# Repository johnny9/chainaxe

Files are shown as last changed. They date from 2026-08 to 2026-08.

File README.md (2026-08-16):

# ChainAxe — Rev A.1



Status: **engineering prototype; not a manufacturing release**  
Updated: 2026-08-16

ChainAxe is a clean-room ESP32-S3 controller for:

- one full S19- or S21-family Bitmain hashboard through the common data cable;
- four AntHat-style 12 V, four-wire Antminer fans with tach feedback and fail-safe full-speed startup;
- a 12–15 V low-current controller input; and
- native USB, Wi-Fi, and an ESP-Miner-derived mining application.

ChainAxe is an independent open-hardware project and is not affiliated with or endorsed by Bitmain. Antminer is a trademark of its respective owner.

The name refers to the complete ASIC hash chain controlled by the board. ChainAxe supersedes the earlier FT4232HQ-based **bitcrane** prototype with a clean ESP32-S3 architecture intended to run ESP-Miner directly.

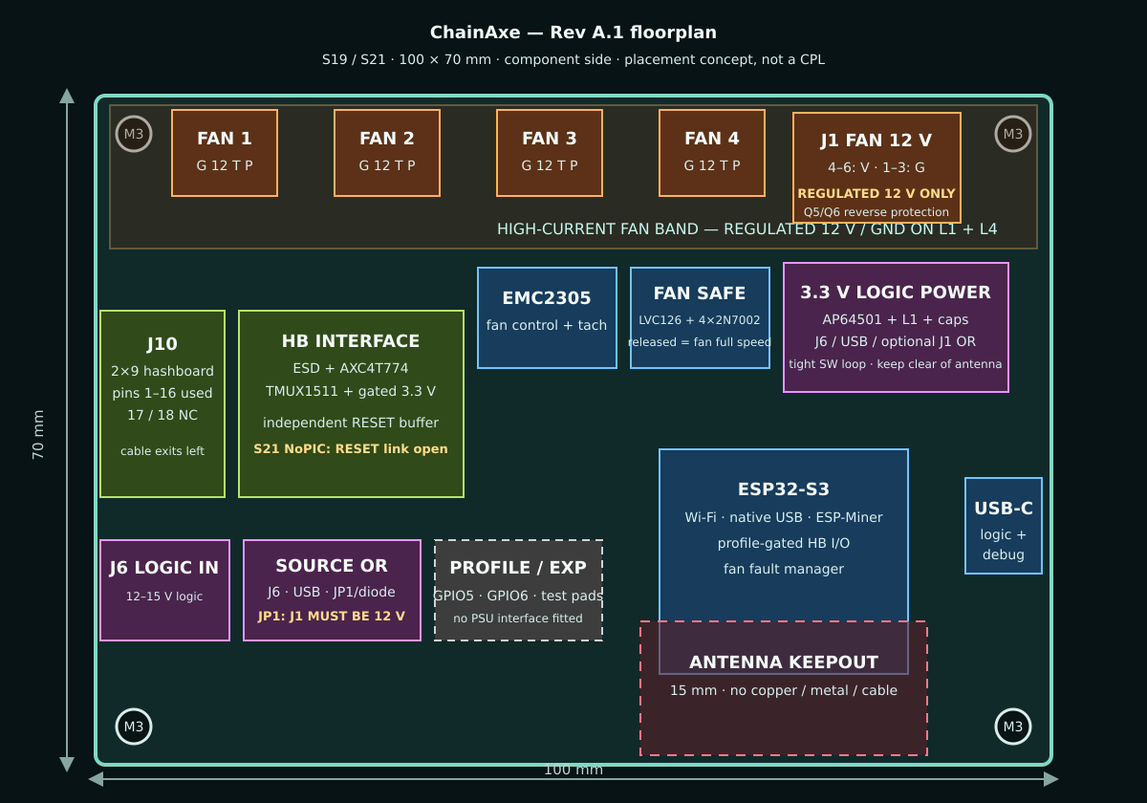
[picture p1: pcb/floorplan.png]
ChainAxe Rev A.1 PCB floorplan


There is **no PSU communication interface in Rev A.1**. Hashboard ASIC/core power remains on its normal external bus bars or bench supply. The ESP board communicates only through the hashboard data cable and drives the four fan connectors.

## Connector interpretation

The retained hashboard connector is physically **2×9 / 18 positions**. Pins 1–16 are used and positions 17–18 are NC, which explains the shorthand “16-pin header.” The user has confirmed this interface is compatible across the intended S19/S21 targets, so Rev A.1 standardizes the cable-side logic domain at 3.3 V and removes the previous target-voltage population matrix.

Compatibility here means the connector and electrical interface are shared. Firmware must still select the correct ASIC family, chip count, address stride, baud sequence, reset policy, and voltage/temperature-control path for the exact hashboard SKU.

## What is here

| Area | Deliverable |
|---|---|
| Architecture | Rail, signal, safety, and power-up decisions in `docs/architecture.md` |
| Target matrix | S19/S21 ASIC/profile scope in `docs/target-matrix.md` |
| Interfaces | Hashboard, fan, power, and USB pin tables in `docs/connector-pinout.md` |
| Schematic entry | Sheet plan and explicit net map in `schematic/` |
| BOM | JLC-oriented engineering BOM and upload template in `bom/` |
| PCB start | 100 × 70 mm floorplan, placement table, stack-up, and routing rules in `pcb/` and `docs/pcb-layout.md` |
| Firmware | ESP-Miner multi-profile porting plan in `firmware/esp-miner-porting-plan.md` |
| Release gates | Review and first-power checklist in `design-review-checklist.md` |
| Validation | Frozen hashes, automated results, and explicit open gates in `VALIDATION.md` |
| Provenance | Repository commits, licenses, and primary datasheets in `sources.md` |

## KiCad project

The editable KiCad 9 baseline is under `hardware/chainaxe/`:

- `chainaxe.kicad_pro` — project and net-class settings;
- `chainaxe.kicad_sch` — preliminary electrical schematic; and
- `chainaxe.kicad_pcb` — 100 × 70 mm unrouted placement baseline.

The KiCad files are intended for engineering review and iteration. They are not released Gerbers. Parts marked provisional or TBD in the engineering BOM must be resolved, the exact connector footprints must be fit-checked, and ERC/DRC must pass in KiCad before an order is placed. KiCad's CLI is not available in this workspace, so the included automated structural, pin-map, and placement-geometry checks are not ERC/DRC results.

The BOM distinguishes exact part candidates from provisional and TBD choices. There are no Gerbers, CPL, or fabrication ZIPs because the exact connector footprints, fan current path, and first supported hashboard profile still require engineering signoff.

## Rev A.1 block architecture

```mermaid
flowchart TD
    F12["12 V fan input"] --> FUSE["External fuse"]
    FUSE --> RPP["Reverse-polarity FETs"]
    RPP --> FANS["Four AntHat-style fan headers"]
    VIN["12–15 V logic input"] --> BUCK["3.3 V logic buck"]
    F12 -. "optional link at 12 V only" .-> BUCK
    USB["USB-C 5 V"] --> BUCK
    BUCK --> ESP["ESP32-S3"]
    ESP --> FANCTL["EMC2305 + fail-safe sinks"]
    ESP --> HBIO["3.3 V gated hashboard interface"]
    HBIO --> HB["18-position / 16-used cable"]
```

The hashboard's ASIC/core current does **not** pass through this controller. Controller ground, fan ground, and hashboard data-cable ground must be common.

## Power-input decision

- `J1 FAN_12V_IN`: high-current, regulated 12 V for the four fans.
- `J6 VIN_LOGIC_12_15`: low-current 12–15 V input for the AP64501 logic regulator.
- `JP1 FAN_TO_LOGIC`: optional fitted link/diode that powers logic from J1 when J1 is verified 12 V.
- USB-C can power logic for flashing with J1/J6 disconnected.

This split is intentional. A nominal 12 V fan must not receive 15 V unless its actual datasheet explicitly permits it. A single 12 V source can power both rails by fitting JP1; a 13–15 V hashboard system needs a separate regulated 12 V fan feed or a future high-current 12 V converter.

## Primary target profiles

- S19 XP / S19k-class BM1366 boards: ASIC driver exists in ESP-Miner; full-board chip counts and power control remain profile-specific.
- S21 BM1368 boards: ASIC driver exists; standard S21 evidence uses 108 chips and requires a NoPIC-aware startup path.
- S21 Pro / S21 XP / S21+ BM1370 boards: chip driver exists; each SKU has a different chip count.
- BM1398 and BM1362 S19-family boards require new ESP-Miner drivers before mining, even though the connector hardware is compatible. The family name alone is not sufficient to select the ASIC.

See `docs/target-matrix.md` for exact scope and evidence levels.

## Recommended first article

1. Review the KiCad schematic pin-by-pin, fit-check every connector and project-local footprint against current manufacturer drawings and real mating parts, and run ERC.
2. Assemble USB, ESP32-S3, AP64501, EMC2305, fan buffer/sinks, and the standardized 3.3 V hashboard interface.
3. Hand-install the 12 V fan, 12–15 V logic, fan, and hashboard connectors on five boards.
4. Validate USB-only and logic-only power first.
5. Validate four genuine Antminer fans from the dedicated 12 V input.
6. Bring up one named hashboard profile with core power current-limited and mining disabled until enumeration, temperatures, and fan interlocks pass.

## Key design choices

- ESP32-S3-WROOM-1-N16R8 retains ESP-Miner's UART pins 17/18.
- A SN74AXC4T774-class buffer operates at 3.3 V on both sides and provides explicit interface enable/disable.
- TPS22917 supplies connector pin 16 with controlled turn-on and reverse-current blocking.
- TMUX1511 is powered from switched `HB_3V3` and uses two of its powered-off-protected channels for the hashboard I²C pair. Local pull-ups stay on controller `3V3`; cable-side pull-ups stay on `HB_3V3`, so an unpowered cable domain cannot be phantom-powered through SDA/SCL.
- RESET has no universal hardware pulldown. Its bias and use are profile-dependent, and the series `RESET_ENABLE_LINK` is DNP/open in the default S21-safe assembly. It is populated with 33 Ω only for a specifically validated legacy-reset profile.
- EMC2305 outputs pass through a disabled-by-default SN74LVC126 and four 2N7002 sinks. With the ESP or buffer unpowered, fan PWM lines float and the fans run full speed.
- Fan motor power uses a calculated low-loss reverse-polarity FET stage, short wide top-and-bottom pours, and an upstream external fuse; it never flows through the AP64501.
- USB D+/− must be routed for 90 Ω differential, ±10%, over continuous ground; the ESP antenna sits at the board edge with a 15 mm keepout.

## Repository conclusions

- `bitaxeNaja` remains useful for ESP32-S3 pin conventions and translated ASIC I/O, but its dual-BM1340 chain is not a full-hashboard reference.
- `aditBoard` supplies the common 18-position/16-used connector map.
- `AntHat` supplies the EMC2305 fan-control pattern and the requested four 12 V fan connector arrangement. Its PSU section is not used.
- Current ESP-Miner supplies BM1366, BM1368, and BM1370 drivers but not BM1398 or BM1362.

## Licensing boundary

This is an original starter specification and does not redistribute the KiCad files or footprint artwork from `aditBoard` or `AntHat`, whose repositories do not state a hardware license. `bitaxeNaja` is CERN-OHL-S-2.0 and ESP-Miner is GPL-3.0; copying their covered hardware or software into a later release carries the corresponding obligations. See `sources.md`.

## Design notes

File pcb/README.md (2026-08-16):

# PCB start

- `floorplan.svg` is the Rev A.1 visual placement concept.
- `floorplan.png` is a rendered review copy of the same drawing.
- `placement.csv` records the synchronized major-block centers from the Rev A.1 KiCad baseline in a board-relative 100 × 70 mm coordinate system.

These are **not** centroid/CPL files and do not enumerate every passive. Final production coordinates must be exported from the routed PCB after connector mating-face orientation and rotations are verified.

The top high-current band distributes regulated 12 V from J1 to four AntHat-style fan connectors. The 12–15 V J6 logic input is a separate low-current domain; the optional JP1/diode feed may link the fan rail into the logic OR only when J1 is truly 12 V. USB can power logic independently.

The common 2×9 hashboard connector uses positions 1–16 and leaves 17/18 NC. Its UART/PLUG translator, I²C switch, gated 3.3 V source, and independent RESET buffer are fitted. The series RESET link is DNP/open in the default S21-safe assembly; fit it only for an exact legacy-reset profile that has passed bench validation.

There is no PSU-control interface in this revision. Consequently the PCB cannot guarantee hard removal of hashboard core power. Fault handling must stop work, use a verified hashboard-local shutdown command if available, disable cable I/O as the profile permits, and release fan PWM for full speed; failed local shutdown requires external power removal.

The module antenna shown at the lower edge assumes that edge is outside a metal enclosure. If the controller is fully inside an Antminer chassis, change U1 to a validated ESP32-S3 external-antenna module and recheck RF compliance and the BOM.

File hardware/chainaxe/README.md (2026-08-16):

# ChainAxe KiCad project

This directory contains the editable Rev A.1 KiCad baseline.

## Files

- `chainaxe.kicad_pro` — KiCad project settings and provisional net classes.
- `chainaxe.kicad_sch` — annotated preliminary schematic.
- `chainaxe.kicad_pcb` — 100 × 70 mm unrouted placement baseline.
- `chainaxe.kicad_dru` — conservative prototype rules.
- `pin-net-audit.csv` — exhaustive expected/actual connection contract for every schematic pin.
- `symbols/ChainAxe.kicad_sym` and `sym-lib-table` — project-local custom symbols.
- `ChainAxe.pretty/` and `fp-lib-table` — nine pinned project-local manufacturer-derived/audited footprints.

Open `chainaxe.kicad_pro` in KiCad 9. KiCad may update generated metadata when the project is first saved; review that diff before committing it.

The source package is structurally checked by `scripts/validate_design.py`. The exhaustive `pin-net-audit.csv` contract is independently checked against physical symbol-pin endpoints by `scripts/validate_schematic_pinmap.py`; that validator explicitly converts KiCad library Y-up coordinates to schematic Y-down coordinates. `scripts/validate_pcb_geometry.py` checks different-net pad intersections, NPTH/copper conflicts, body/courtyard collisions, and undocumented edge overhangs. All three are dependency-free CI checks. This build environment does not include `kicad-cli`, so a local KiCad 9 ERC/DRC run remains mandatory before any fabrication export; none of the source validators replaces it.

Fan startup is hardware-defined: R105 holds `FAN_ARM` low, while R106–R109 hold the four EMC2305 PWM inputs to U8 low. This keeps the open-drain fan sinks released (the supported-fan full-speed-safe state) even if firmware asserts `FAN_ARM` before configuring the EMC2305. J30's audit enumerates every USB4105-GF-A signal/power contact; its A9/B9 VBUS and A12/B12 ground contacts are stacked on their shared logical nets. The official footprint numbers all four conductive shell stakes as `S1`, so one audited `S1` pin owns that common shell net.

C112 is the populated 100 nF USBLC6 VBUS bypass and must sit directly beside U9 pins 5/2. C3, the optional 220 µF 3V3 bulk footprint, is native DNP until AP64501 loop and load-transient validation proves an appropriate bulk value.

## Design status

This is an engineering-entry design, not an order-ready board. The schematic and PCB capture the intended architecture, safe startup states, connector map, and major candidate parts. The following remain release blockers:

- real-mating-part fit and keyed circuit-view checks for J1, J2–J6, J10, and USB-C; J6's exact connector/part remains a stop-order choice;
- fan current, inrush, reverse-polarity FET, connector, copper, and thermal calculations;
- AP64501 feedback, compensation, inductor, capacitance, and thermal verification;
- ESD/TVS clamping analysis and final ordering codes;
- exact first hashboard SKU/profile, including RESET policy and local voltage-off behavior;
- KiCad ERC, PCB synchronization, routing, stack-up impedance calculation, and DRC; and
- JLCPCB assembly preview, BOM/CPL reconciliation, and first-article review.

Do not generate production Gerbers from this baseline without closing the stop-order gates in `../../design-review-checklist.md`.

## PCB intent

The PCB is intentionally unrouted. The fan-current band stays at the top/right edge, the J10 interface lane stays at the left edge, and the ESP32-S3 antenna faces the bottom board edge with a 15 mm keepout. The `USB_90OHM_PLACEHOLDER` and `FAN_POWER_PROVISIONAL` net classes are reminders, not validated geometries.

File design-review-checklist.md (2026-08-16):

# Rev A.1 design-review and release checklist

Any unchecked item in **Stop-order gates** blocks Gerber/CPL release.

## Stop-order gates

- [ ] At least one initial profile is frozen with exact miner SKU, hashboard assembly/revision, ASIC type/count, PIC/NoPIC architecture, and captured factory startup sequence.
- [ ] J10 is a common keyed 2×9, 18-position cable connector; positions 1–16 match the documented map and 17/18 are confirmed NC.
- [ ] TX, RX, PLUG, SDA, SCL, pin-16 3.3 V, and profile-specific RESET behavior are verified on the exact target.
- [ ] S21 BM1368 NoPIC assembly leaves `RESET_ENABLE_LINK` open, and its profile is also proven never to enable the independent RESET buffer in boot, operation, watchdog, update, restart, and fault paths.
- [ ] Initial and operational UART baud, ASIC enumeration count, voltage-control path, telemetry, and local shutdown command are established per supported profile.
- [ ] Exact AntHat-style fan MPN, connector/key orientation, 12 V current, startup/stall current, tach pulses/revolution, and safe minimum RPM are recorded.
- [ ] J1 is labeled and protected for exact regulated 12 V fan power; J6 is labeled and protected for 12–15 V logic power.
- [ ] J1 pins 1–3 are GND and 4–6 are `FAN_12V_RAW`, matching the reviewed AntHat source and the final mating-face drawing.
- [ ] Q5/Q6 reverse-polarity FET count, SOA, current sharing, Rds(on), copper, and thermals pass measured simultaneous fan startup/stall current.
- [ ] JP1 cannot connect J1 to logic without an explicit `12V ONLY` assembly choice, and every J1/J6/USB combination is reverse-isolated.
- [ ] System-level safety review accepts that this revision cannot hard-remove hashboard core power and documents the external disconnect procedure.

## Schematic review

- [ ] Every external cable line has an intentional default state and connector-side ESD decision.
- [ ] U5/TPS22917 is populated; source/sink direction, reverse current, rise time, QOD choice, and pin-16 load are checked.
- [ ] U6/SN74AXC4T774 is populated; channel directions, `/OE` polarity, Ioff/partial-power behavior, and maximum profile baud are checked.
- [ ] U7/TMUX1511 is populated from `HB_3V3`; its exact TSSOP-14 pin map, powered-off isolation, two used channels, grounded unused selects, 100 nF decoupling, pull-ups, and enable sequencing are checked.
- [ ] Hashboard I²C rise time, low-level sink current, bus capacitance, and overshoot are measured at 100 kHz and the intended operating rate; `HB_I2C_EN` is low before every `HB_3V3` ramp.
- [ ] U12 RESET buffer has an enable independent of U6 and defaults high-impedance with an ESP reset or unpowered.
- [ ] No fixed pull-up/pull-down on HB_RESET can violate an S21 NoPIC profile; any optional bias is visibly DNP/profile-specific.
- [ ] Every A0/A1/A2 high strap connects only to switched `HB_3V3`; the corresponding low/high population pair cannot be fitted incorrectly.
- [ ] The default S21-safe DNP RESET link provides a firmware-independent open circuit during ESP bootloader, brownout, crash, update, and USB-only operation.
- [ ] J10 pins 17 and 18 are electrically NC.
- [ ] AP64501 feedback, inductor, input/output capacitance after DC bias, transient response, loss, and thermal rise are calculated over J6 = 12–15 V.
- [ ] Logic-source OR cannot backfeed USB, J1, or J6; USB-only power leaves fan sinks released, HB_3V3 off, UART/I²C disabled, and RESET high-impedance.
- [ ] JP1 and its diode are rated for the logic load and not treated as a way to operate 12 V fans from 15 V.
- [ ] EMC2305 address and hardware 100%-speed startup decode are checked against the current datasheet.
- [ ] Fan-driver polarity is traced end-to-end: command → EMC output → buffer → NMOS → fan PWM input.
- [ ] `FAN_ARM` defaults inactive and cannot assert before verified 100% command/readback.
- [ ] `EMC_PWM1..4` each have a populated 100 kΩ pulldown at U8, and the early-arm fault case is bench-tested to keep fan PWM released/full speed.
- [ ] Every supported fan is proven to provide a compatible internal PWM pull-up and to request full speed when the controller sink is released; Rev A.1 has no external PWM pull-up rail.
- [ ] ESP strapping pins 0/3/45/46 are not used for operational safety outputs.
- [ ] No PSU-control connector, enable circuit, bus, GPIO assignment, or misleading power-cut label remains.
- [ ] ERC has no unexplained power, unconnected, or conflicting-driver warnings.

## PCB / mechanical review

- [ ] Manufacturer drawings are used for every high-current and cable connector footprint.
- [ ] 1:1 paper fit and real mating-connector fit are complete for J1, J2–J6, J10, and J30.
- [ ] J30's drawing-derived USB4105-GF-A footprint is verified by 1:1 print and real-part fit, including every VBUS/GND contact, through-hole shell stake, locating peg, board-edge datum, and pin-1 orientation.
- [ ] J10 mating-face pin 1, 2×9 keying, and no-connect positions 17/18 match the cable.
- [ ] Fan pin 1 and `G 12 T P` functions are visible after assembly and match the AntHat-style harness.
- [ ] `FAN 12V ONLY` and `LOGIC 12–15V` are distinct, legible labels; JP1 carries a `CLOSE ONLY WITH 12V J1` warning.
- [ ] Selected JLC four-layer stack is entered in KiCad and USB is solved for 90 Ω differential, ±10%.
- [ ] L2 is continuous ground under USB, UART, I²C, tach, ESP, and buck control routes.
- [ ] ESP antenna is outside/at the chassis boundary with 15 mm copper/component/metal/cable keepout, or U1 is changed to a validated external-antenna module.
- [ ] Fan-current path is reviewed from the upstream external fuse/wiring through J1 contacts, Q5/Q6, pad, neck, pour, via field, and each branch connector.
- [ ] IPC-2152/current-density analysis uses measured simultaneous startup/stall current and selected copper weight.
- [ ] Prototype thermography confirms connector, fuse, pour, and via-field temperature rise at worst case.
- [ ] Buck hot loop and SW node are compact; FB is quiet; exposed-pad thermal vias and paste windows are reviewed.
- [ ] J1, J6, USB, fan, and hashboard ESD/TVS returns reach connector ground without crossing sensitive logic returns.
- [ ] U12 and its 33 Ω RESET resistor are routed independently from UART enable and placed close to the J10 interface.
- [ ] DRC passes final JLC rules; there is no silkscreen over pads and solder-mask slivers meet the chosen process.

## BOM / JLC assembly review

- [ ] Every LCSC code is reopened at quote time and matched to manufacturer, exact MPN, package, lifecycle, and stock.
- [ ] Basic/extended/THT handling and minimum quantities are accepted.
- [ ] DNP and hand-install lists agree across schematic, BOM, CPL, assembly drawing, and README.
- [ ] U5, U6, U7, U12, their default-enable resistors, and connector-side protection are fitted in the intended Rev A.1 variant.
- [ ] JP1 is open by default and assembly notes prevent automatic solder bridging.
- [ ] CPL rotation/side and pin 1 are inspected in JLC's assembly preview for every fitted part.
- [ ] QFN exposed-pad and THT paste openings are inspected; no accidental open-hole paste remains.
- [ ] A five-board first article is ordered and reviewed before volume assembly.

## Bring-up / DVT

- [ ] Bare-board continuity and isolation pass between FAN_12V, VIN_LOGIC_12_15, LOGIC_IN, USB_VBUS, 3V3, and HB_3V3.
- [ ] Current-limited USB-only, J6 = 12 V, J6 = 15 V, and J1 = 12 V power-ups pass before J10/fans are installed.
- [ ] No test applies more than 12 V to J1 or the fan connectors.
- [ ] Hardware defaults are measured before firmware: fan PWM sinks released, HB_3V3 off, UART/I²C disabled, RESET high-impedance, and JP1 open.
- [ ] Four fans start at full speed before `FAN_ARM`; every unplug/stall produces the expected fault.
- [ ] Hashboard cable is first tested with core power disabled and all interface outputs disabled.
- [ ] Each released profile enumerates its configured ASIC count on 100 cold starts and has clean readback at its final baud.
- [ ] S19 XP/S19k-class BM1366, S21 BM1368, and BM1370-family testing is tracked as separate profiles rather than inferred from connector compatibility.
- [ ] Fault injection stops work, attempts verified local shutdown when supported, disables cable I/O as permitted, preserves profile-safe RESET behavior, and releases fans to full speed.
- [ ] A failed local shutdown test explicitly demonstrates and documents the required external hashboard power removal.
- [ ] A 24-hour conservative mining soak passes before frequency/voltage exploration for each released profile.

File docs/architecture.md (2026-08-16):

# Rev A.1 architecture

Rev A.1 is an ESP32-S3 miner/controller for one S19- or S21-family Bitmain hashboard and four AntHat-style 12 V fans. It talks to the hashboard only through the common data cable. Hashboard ASIC/core power remains on the external bus bars; there is no PSU connector, PSU enable signal, or PSU telemetry interface on this revision.

This is a schematic-entry architecture, not a production-qualified power controller. Every mining-capable firmware build must select one exact, tested hashboard profile.

## System boundary

```mermaid
flowchart TD
    FANIN["J1: regulated 12 V"] --> RPP["Reverse-polarity FETs"]
    RPP --> FANBUS["Protected fan bus"]
    FANBUS --> FH["Four 4-wire fans"]
    VIN["J6: logic 12-15 V"] --> ORING["Logic-input OR"]
    USB["USB-C 5 V"] --> ORING
    FANBUS -. "JP1; 12 V only" .-> ORING
    ORING --> BUCK["AP64501 3.3 V"]
    BUCK --> ESP["ESP32-S3 + fan control"]
    ESP --> HBIO["Gated 3.3 V cable I/O"]
    HBIO --> HB["S19/S21 hashboard"]
```

The controller does not carry hashboard core current. Fan return, controller ground, and hashboard cable ground are common; the external hashboard power system must share that reference.

## Power domains

| Domain | Source | Intended load | Design rule |
|---|---|---|---|
| `FAN_12V` | `J1 FAN_12V_IN` through Q5/Q6 | Four fan motor supplies | Regulated 12 V only; size connector, reverse-polarity FETs, fuse, pours, and wiring from the actual fan nameplate current and inrush |
| `VIN_LOGIC_12_15` | `J6` | Controller logic | 12–15 V, low current; protected before the logic-input OR node |
| `USB_5V` | USB-C | Controller-only bring-up | Must not backfeed J1, J6, fan motor power, or hashboard pin 16 |
| `LOGIC_IN` | diode/ideal-diode OR of J6, USB, and optional J1 link | AP64501 input | Source isolation is required; populate `JP1 FAN_TO_LOGIC` only when J1 is a verified 12 V rail |
| `3V3` | AP64501 | ESP32-S3, EMC2305, buffers, sensors | Local logic rail |
| `HB_3V3` | 3V3 through TPS22917 | Hashboard cable pin 16 | Default off; reverse-current blocking; enabled only after a profile and cable checks pass |

A 15 V source must never be routed directly to nominal 12 V fans. A single regulated 12 V supply can feed both J1 and the logic regulator when JP1 is deliberately fitted. For a 13–15 V system, provide a separate regulated 12 V fan source; a future revision could add a high-current fan buck after the current requirement is known.

Recommended protection at schematic entry:

- an upstream, replaceable external fuse sized for all fan startup current and located close to the 12 V source;
- a low-loss high-current P-channel MOSFET reverse-polarity stage on J1, starting with two parallel `DMP3013SFV-7` candidates plus a gate resistor/Zener clamp; one device is not assumed to carry four-fan startup current, and the final FET count/thermal design must follow measurement;
- a series Schottky reverse-block/OR diode on J6 and a bidirectional `SMBJ18CA`-class provisional TVS so a normal reversed input does not forward-bias the shunt protector;
- an `SMBJ13A`-class starting TVS candidate on the protected 12 V fan bus, with standoff, clamp, pulse energy, and fan tolerance verified before release;
- bulk capacitance beside the fan input and each connector group, and local high-frequency decoupling at every IC; and
- no copper path that makes the AP64501 carry fan motor current.

## Hashboard cable interface

J10 is physically 2×9 / 18 positions. Positions 1–16 carry the common Bitmain signals and 17–18 are NC. Rev A.1 treats every cable-side logic signal as 3.3 V; exact pin mapping is in `connector-pinout.md`.

| Function | Circuit | Safe default |
|---|---|---|
| Pin-16 supply | TPS22917 load switch from 3V3 | Off by GPIO10 pulldown; reverse-current blocking |
| UART TX/RX and `PLUG` | SN74AXC4T774-class buffer, both sides at 3.3 V | Disabled by GPIO7 pull-up on active-low OE |
| SDA/SCL | Two channels of TMUX1511, powered by switched `HB_3V3`; local pull-ups to `3V3`, cable pull-ups to `HB_3V3` | Powered-off isolation when `HB_3V3` is absent; GPIO9 pulldown keeps both selects low |
| RESET | Independent SN74LVC1G125-class tri-state buffer plus DNP series `RESET_ENABLE_LINK` | Physical cable path open in the default S21-safe assembly; 10 kΩ pull-up also keeps the buffer high-impedance |
| A0/A1/A2 | 4.7 kΩ default-low straps plus mutually exclusive solder options to switched `HB_3V3` | Address 0; any nonzero setting is an explicit assembly/profile choice; never strap to always-on 3V3 |

The reset path is intentionally separate from the UART/plug buffer. GPIO1 carries the reset command and GPIO4 separately enables the reset driver. A 10 kΩ pull-up keeps the active-low enable inactive. There is no universal populated pull-up or pull-down on the cable RESET net; optional bias pads are DNP until the exact target proves a safe value. The series `RESET_ENABLE_LINK` is also DNP/open by default, which makes the first S21 BM1368 NoPIC assembly physically incapable of driving J10 RESET. A legacy-reset profile may populate that link with 33 Ω only after its exact reset sequence is validated. Public S21 work warns that legacy GPIO reset can collapse the hashboard's TAS5782M DAC-generated voltage.

Series resistors near the controller should be fitted on push-pull cable outputs, with footprints for damping adjustment after scope measurements. Put low-capacitance ESD parts at J10 without creating stubs. The connector shell/key/orientation and mating part remain procurement signoff items even though the signal map is fixed.

U7 is deliberately not a conventional dual-rail I²C level translator. The TMUX1511 is a bidirectional signal switch with powered-off protection to 3.6 V and fail-safe select inputs. Supplying it from `HB_3V3` makes both I²C paths high-impedance whenever the hashboard I/O supply is off, even while the controller-side pull-ups remain at 3.3 V. Only channels 1 and 2 are used; channels 3 and 4 are held off. The two 4.7 kΩ pull-up pairs appear in parallel while enabled, so the effective pull-up is about 2.35 kΩ. Firmware must deassert `HB_I2C_EN` before intentionally ramping `HB_3V3`, and the real cable must be checked for rise time, low-level margin, capacitance, and overshoot below the switch's 3.6 V powered-off limit.

## Fan subsystem

Each of four connectors follows the AntHat-style logical order `GND, +12V, TACH, PWM` and must use the same proven physical family and orientation at schematic release. The EMC2305 monitors tach and produces four PWM commands. Each command passes through a disabled-by-default SN74LVC126 stage and an external 2N7002 open-drain sink:

- `FAN_ARM` (GPIO8) is held low by hardware until firmware has configured and read back the EMC2305;
- 100 kΩ pulldowns on `EMC_PWM1..4` hold the buffer inputs low while the EMC2305 outputs are still open-drain at power-on, so even an erroneous early `FAN_ARM` leaves the external PWM sinks released;
- when the ESP, EMC2305, or buffer is unpowered, the sink gates remain inactive and PWM wires float;
- supported four-wire fans therefore use their internal pull-ups and request full speed on a floating PWM line; fans that do not provide a compatible internal PWM pull-up are outside the Rev A.1 supported profile.

Tach inputs need ESD protection, optional RC filtering, and voltage clamps compatible with the EMC2305 input limits. Firmware must validate tach age and plausible RPM on all configured required fans before mining.

## GPIO allocation

| GPIO | Function |
|---:|---|
| 1 | Hashboard RESET command input to independent tri-state buffer |
| 4 | `HB_RESET_OE_N`; pulled high |
| 5, 6 | Reserved expansion/test pads |
| 7 | Active-low hashboard UART/PLUG buffer OE; pulled high |
| 8 | `FAN_ARM`; pulled low |
| 9 | Hashboard I2C switch enable; pulled low |
| 10 | Hashboard pin-16 3.3 V enable; pulled low |
| 11 | Protected/divided rail monitor ADC |
| 12 | Hashboard `PLUG` input |
| 13 | EMC2305 ALERT input |
| 14, 21 | Hashboard SDA/SCL |
| 17, 18 | ASIC UART TX/RX |
| 47, 48 | Local EMC2305 SDA/SCL |

USB uses the ESP32-S3 native USB pins and must follow Espressif's routing and antenna guidance.

## Startup and fault ownership

Hardware pull resistors establish a safe state before the ESP boots: fans request full speed, hashboard pin 16 is off, UART/I2C/reset drivers are high-impedance, and mining is impossible. One firmware safety state machine owns every interface enable and the `mining_allowed` decision.

Because Rev A.1 intentionally omits PSU control, it cannot guarantee removal of externally supplied hashboard core power. On a fault it can stop sending work, issue a tested hashboard-local I2C shutdown/voltage-off command when the selected profile supports one, disable cable interfaces in the profile-defined safe order, and release fan PWM for full-speed cooling. If the local shutdown path is absent or fails, the external supply must be disconnected by the operator or an independent protection system. This limitation must remain visible in the UI and release documentation.

## Profile boundary

Connector compatibility does not make the ASIC protocol universal. Each firmware profile must fix at least the ASIC family, chip count, address stride, initial and operating baud, reset policy, I2C devices, voltage-control sequence, temperature interpretation, and shutdown behavior. Unknown or ambiguous boards remain in diagnostic mode. The current priority is BM1368 S21, followed by exact BM1366 S19 XP/S19k profiles and then BM1370 S21 variants; see `target-matrix.md`.

## PCB consequences

- Keep the high-current fan band at the board edge and away from USB, the ESP antenna, UART, tach, and I2C routing.
- Route J1-to-fan power with short top-and-bottom pours and dense via stitching; calculate width and connector temperature rise from the measured worst-case current.
- Keep J6/logic protection and AP64501 switching loops compact and physically separate from fan PWM/tach and the ESP antenna.
- Place all J10 protection, series resistors, translators, and load switch in one short interface lane at the cable connector.
- Expose test points for J1, J6, LOGIC_IN, 3V3, HB_3V3, fan PWM/tach, UART, I2C, RESET, all OEs, and ground.
- Preserve the ESP module's board-edge antenna position and 15 mm copper/component keepout.

## Release blockers

Before fabrication release, capture the exact S19/S21 cable connector manufacturer/part number, fan connector family/orientation, fan maximum current and inrush, protection ratings, AP64501 magnetics/compensation, exact first hashboard SKU, and a verified local voltage-off path. Before enabling mining, prove interface waveforms, full-chain enumeration, thermal sensing, all four fan-fault paths, watchdog behavior, and the limitations of shutdown without PSU control.

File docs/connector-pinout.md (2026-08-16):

# Connector pinout and cable rules

All connector drawings and silkscreen must identify the **mating-face view**. A bottom-mounted or right-angle connector can mirror what the designer sees in KiCad. Verify orientation, keying, and pin 1 with continuity testing before applying power.

## J10 — common Bitmain hashboard data cable

Rev A.1 uses the common 2×9, 2.00 mm, 18-position Bitmain data connector. The electrical interface occupies positions 1–16; positions 17 and 18 remain no-connect. This preserves the cable form used by the target S19/S21 families even though it is often informally called a “16-pin” interface.

Proposed connector: right-angle female `PM200-2-09-W-4.3` / LCSC `C3012192`, pending a real-cable fit check and a manufacturer-drawing footprint audit.

| Pin | Net | Rev A.1 treatment | Direction at controller |
|---:|---|---|---|
| 1 | GND | Cable ground | — |
| 2 | GND | Cable ground | — |
| 3 | HB_SDA | TMUX1511 powered-off-protected switch; cable pull-up to `HB_3V3` | Bidirectional |
| 4 | HB_SCL | TMUX1511 powered-off-protected switch; cable pull-up to `HB_3V3` | Bidirectional |
| 5 | HB_PLUG | SN74AXC4T774 channel, ESD protected | Input |
| 6 | HB_A2 | 4.7 kΩ default low; mutually exclusive option to switched `HB_3V3` | Static strap |
| 7 | HB_A1 | 4.7 kΩ default low; mutually exclusive option to switched `HB_3V3` | Static strap |
| 8 | HB_A0 | 4.7 kΩ default low; mutually exclusive option to switched `HB_3V3` | Static strap |
| 9 | GND | Cable ground | — |
| 10 | GND | Cable ground | — |
| 11 | HB_TX | SN74AXC4T774 channel + 33 Ω source resistor | Output to hashboard |
| 12 | HB_RX | SN74AXC4T774 channel + 33 Ω damping resistor | Input from hashboard |
| 13 | GND | Cable ground | — |
| 14 | GND | Cable ground | — |
| 15 | HB_RESET | Independent tri-state reset buffer through `RESET_ENABLE_LINK` | Physical link DNP/open for default S21-safe assembly; fit 33 Ω only for a validated legacy-reset profile |
| 16 | HB_3V3 | Controller-supplied 3.3 V through U5/TPS22917 | Power output |
| 17 | NC | No connection | — |
| 18 | NC | No connection | — |

U5, the UART/PLUG translator, and the I²C switch are populated in Rev A.1. Their enables default inactive so an unconfigured ESP cannot drive the cable. The reset path has a separate output-enable signal from the normal UART enable; a profile may use UART and I²C while leaving RESET electrically high-impedance.

### Reset rule

RESET is not a universal startup primitive. The selected hashboard profile owns its polarity, level, timing, and whether it may be driven at all. In particular, the S21 BM1368 NoPIC assembly leaves `RESET_ENABLE_LINK` open and its firmware must **never enable the controller reset buffer**. A firmware update or fault handler must not bypass this rule.

### Cable validation

1. With both systems unpowered, trace cable pin 1 to ground and establish the mating-face orientation.
2. Confirm that positions 17 and 18 are unused on the exact board and cable.
3. Record the exact miner model, hashboard assembly/revision, ASIC type/count, and original-controller startup capture.
4. Power Rev A.1 with the hashboard's core rail off for the first interface test. Confirm 3.3 V at pin 16 and high-impedance UART/I²C/RESET before enabling one interface at a time.
5. Do not connect an unprofiled or unknown hashboard merely because the cable fits.

## J2–J5 — AntHat-style 12 V four-wire fans

Use the AntHat 2×2 candidate, Molex `0353180420` / LCSC `C54909`, and match the actual fan harness before releasing the footprint. Redraw it from Molex's current drawing rather than copying AntHat's custom combo footprint. Print the electrical order beside every connector as `G 12 T P`; do not rely on wire color.

| Pin | Signal | Notes |
|---:|---|---|
| 1 | GND | High-current motor return |
| 2 | FAN_12V | Exact regulated 12 V motor rail from J1 |
| 3 | TACHn | Open-collector/open-drain tach; pulled to 3.3 V |
| 4 | PWMn | External 2N7002 open-drain control; hardware default released for full speed |

Connector views in fan documentation can show these functions in the opposite visual order. Treat that as an orientation issue, not permission to swap functions. Validate pin 1, keying, power polarity, tach pulses/revolution, and PWM behavior on the actual AntHat fan before mating it to Rev A.1.

## J1 — regulated 12 V fan input

J1 is the high-current fan input. It must receive a regulated **12 V** supply suitable for the measured simultaneous startup/stall current of all four fans. Do not feed J1 with 15 V.

Proposed connector: Molex `0455580003` / LCSC `C492365`, using a datasheet-derived 2×3 THT footprint with three contacts paralleled per rail. AntHat uses this part for its input, but Rev A.1 restricts it to regulated 12 V fan power.

| Pins | Net |
|---|---|
| 1, 2, 3 | GND |
| 4, 5, 6 | FAN_12V_RAW |

This polarity follows the reviewed AntHat source. `FAN_12V_RAW` passes through the Q5/Q6 reverse-polarity stage before it becomes the protected `FAN_12V` bus. Do not reuse AntHat's custom footprint: generate a fresh footprint from the connector manufacturer's current drawing, print it 1:1, and perform a real-part fit check.

## J6 — 12–15 V logic input

J6 is a separate, low-current input for the controller buck regulator.

| Pin | Net | Notes |
|---:|---|---|
| 1 | VIN_LOGIC_12_15 | 12–15 V DC input, protected before the logic-power OR |
| 2 | GND | Logic return |

JP1 and its series diode provide an optional `FAN_12V → LOGIC_IN` feed. Close JP1 only when J1 is known to be a regulated 12 V source. The controller may instead be powered from J6 or USB. The OR network must prevent any source from backfeeding USB, J6, or the fan rail.

## J30 — USB-C device/debug

USB 2.0 device-only receptacle:

- CC1 and CC2: separate 5.1 kΩ pull-downs to GND.
- D+/D−: USBLC6-2SC6-class low-capacitance ESD, then matched 22–33 Ω series resistors near the ESP.
- VBUS: logic-power OR input and VBUS sense only; never connected directly to J1 or J6.
- Schematic-owned contacts: A4/A9/B4/B9 = `USB_VBUS`; A1/A12/B1/B12 = `GND`; A5/B5 = CC1/CC2; A6/B6 = D+; A7/B7 = D−; A8/B8 = NC; all four conductive shell stakes share pad number S1 = `USB_SHIELD`, matching the official KiCad/GCT footprint.
- The project-local USB4105-GF-A footprint vendors the official KiCad 8.0.9/GCT drawing-derived geometry, including every duplicated contact, four through-hole shell stakes, and two locating pegs; a real-part first-article fit check remains mandatory.
- USB-only power must leave fan sinks released, HB_3V3 off, UART/I²C disabled, and RESET high-impedance.
- Shield: configurable chassis/ground treatment; initial 1 MΩ ∥ 1 nF option plus a short ESD return, subject to enclosure strategy.

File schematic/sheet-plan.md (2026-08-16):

# KiCad schematic-entry plan — Rev A.1

Create a hierarchical KiCad project with the following sheets. Rev A.1 is a direct S19/S21-family hashboard and four-fan controller; it has no PSU communication or PSU-enable interface.

## Sheet 1 — root / connectors

- J1 regulated 12 V high-current fan input (`FAN_12V`); this rail must not exceed the connected fans' rating.
- J6 low-current 12–15 V controller input (`VIN_LOGIC_12_15`).
- JP1 optional fan-rail-to-logic-input feed, fitted only when J1 is a verified regulated 12 V source.
- J2–J5 AntHat-style four-wire 12 V fan headers, silk-labeled `G / 12 / T / P`.
- J10 common Bitmain 2×9, 18-position hashboard data connector; positions 1–16 active and 17–18 NC.
- J30 USB-C for native USB and optional logic power.
- Hierarchical pins for each functional sheet.
- Four mounting holes, fiducials, and a labeled test-point table.

## Sheet 2 — power

- Three-source logic-input OR: J6 through D1, the JP1-qualified J1 feed through D2, and USB VBUS through D3.
- AP64501 3.3 V buck and complete compensation/feedback cell.
- J1 `FAN_12V_RAW` through two provisional parallel Q5/Q6 high-side P-channel reverse-polarity FETs, with gate resistor and 12 V Zener clamp, then D4 on the protected `FAN_12V` bus. Recalculate FET count and copper from measured current.
- J6 series D1 reverse-block/OR diode and a bidirectional D5 TVS appropriate to 12–15 V. Do not join the high-current fan path to the logic-input path except at the explicit JP1/D2 option.
- U5 TPS22917, populated, switches controller 3.3 V to `HB_3V3` and J10 pin 16.
- Rail-monitor divider, RC filter, and labeled test points.
- Copper/fusing note: J1 and J2–J5 carry fan current; J6, JP1, and the OR diodes carry controller current only.

## Sheet 3 — ESP32-S3

- ESP32-S3-WROOM-1-N16R8.
- Native USB protection and source-series resistors.
- EN RC/reset button and GPIO0 boot button.
- Debug UART/test pads; GPIO5 and GPIO6 reserved as labeled expansion/test pads.
- Local bulk and high-frequency decoupling.
- Explicit no-connects and antenna keepout note.

## Sheet 4 — hashboard interface

- U6 SN74AXC4T774-class 3.3 V-to-3.3 V gated interface for UART TX, UART RX, and PLUG.
- U7 TMUX1511PWR powered-off-protected switch, supplied by switched `HB_3V3`; use channels 1 and 2 for SCL/SDA, tie both selects to `HB_I2C_EN`, ground unused selects, and leave unused signal pins NC.
- 4.7 kΩ pull-ups on controller SCL/SDA to always-on `3V3`, and separate 4.7 kΩ cable-side pull-ups to switched `HB_3V3`.
- U12 independent SN74LVC1G125-class reset buffer: GPIO1 is reset data and GPIO4 is active-low output enable.
- 10 kΩ pullup on `HB_RESET_OE_N`; no fixed connector-side reset pulldown. Provide mutually exclusive optional bias pads and leave them DNP.
- DNP/open `RESET_ENABLE_LINK` between U12 and the cable-side 33 Ω position. The default S21-safe assembly leaves this physical path open; populate 33 Ω only for a validated legacy-reset target.
- Large schematic warning: the S21 BM1368 NoPIC profile must leave the link open and never enable or toggle U12.
- A0/A1/A2 default-low resistors and mutually exclusive high straps to switched `HB_3V3` only; never to always-on `3V3`.
- Connector-side ESD arrays and 33 Ω source-series options.
- Safe-state pulls on U5 enable, U6 OE, U7 enable, and U12 OE.

## Sheet 5 — fan controller

- EMC2305 with exposed pad, decoupling, 22 kΩ `CLK`, and 33 kΩ `ADDR_SEL` straps.
- SN74LVC126-class buffer disabled by `FAN_ARM` at reset, with 100 kΩ pulldowns on all four `EMC_PWM` inputs, followed by four 2N7002 open-drain PWM sinks.
- No controller-side PWM pull-up rail; supported AntHat-style four-wire fans must provide their own compatible PWM pull-ups.
- Four 36 kΩ tach pull-ups to 3.3 V.
- ALERT pull-up and test points.
- `FAN_ARM` hardware pulldown, four buffer-input pulldowns, and individual MOSFET gate pulldowns.
- Optional RC/ESD footprints at external fan signal lines; populate only after signal-integrity review.

## Sheet 6 — expansion / test

- Labeled GPIO5/GPIO6 expansion pads with ground and 3.3 V nearby.
- Programming/debug access and test points for all rails and external signals.
- Profile/assembly-variant identification pads.
- No PSU connector, PSU control net, or PSU communications circuitry.

## ERC conventions

- Name every voltage domain: `FAN_12V`, `VIN_LOGIC_12_15`, `USB_VBUS`, `LOGIC_IN`, `3V3`, and `HB_3V3`.
- Use net ties only where a documented single-point connection is required; do not silence ERC with generic power flags.
- Mark DNP alternatives with assembly variants and mutually exclusive population groups.
- Add a note beside every external connector specifying the drawing view and pin-1 indicator.
- Include source URL, datasheet revision, and footprint-drawing revision as symbol/footprint properties for critical parts.

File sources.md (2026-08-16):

# Source and license record

Accessed 2026-08-16. Repository commits are pinned where a reviewed revision was available. Part availability, board variants, and external documentation can change; revalidate them before design release.

## Requested hardware repositories

### bitaxeNaja

- Repository: https://github.com/bitaxeorg/bitaxeNaja
- Reviewed master commit: `6d815ef05288b3079a94567eb02c4e73d85dd82d`
- License: CERN Open Hardware Licence Version 2 — Strongly Reciprocal (`CERN-OHL-S-2.0`).
- Applicable facts: ESP32-S3-WROOM-1-N16R8 conventions, native USB implementation, and buffered ASIC signals.
- Boundary: Naja is a short, dual-BM1340 chain and is not proof of signal integrity, power sequencing, or firmware behavior on a full S19/S21 hashboard.

### aditBoard

- Repository: https://github.com/skot/aditBoard
- Production v2 revision reviewed: https://github.com/skot/aditBoard/tree/1c260d8767b7821e2b2d7aa110d65c469ff71d2d
- Firmware reference: https://github.com/skot/aditboard-firmware
- No hardware license was found in the repository. Use it as interface evidence; do not copy or redistribute its KiCad artwork or custom footprints without permission.
- Applicable facts: common 2×9 / 18-position cable connector, with signal positions 1–16 and positions 17–18 NC; USB/UART/I2C/GPIO bridge topology.
- Boundary: its firmware is a bridge rather than a miner, and the exact cable connector manufacturer/part number still needs procurement verification.

### AntHat

- Repository: https://github.com/skot/AntHat
- Master revision reviewed: `5a05b5dd6bb5a9b8b767a26e3bf38c463c0e4669`
- Newer v3 branch head inspected: `24fcf0eb23e5fd2e0015a6cf52990735f914ed60`
- No hardware license was found. Redraw circuits/footprints from manufacturer documentation or obtain permission before copying source artwork.
- Applicable facts: EMC2305 fan-control concept, four 12 V four-wire fan interfaces, logical fan pin order `GND, 12V, TACH, PWM`, Molex `0353180420` / LCSC `C54909` as the 2×2 fan-connector candidate, and Molex `0455580003` / LCSC `C492365` as its input connector. The reviewed source assigns input pins 1–3 to GND and 4–6 to VIN, and uses a DMP3013SFV-based reverse-polarity stage; Rev A.1 expands that stage provisionally for the four-fan load.
- Boundary: Rev A.1 intentionally does not use AntHat's PSU section.

## Hashboard and firmware evidence

- ESP-Miner baseline: https://github.com/bitaxeorg/ESP-Miner/tree/d3dbcc51d11d33b7579baac8c5b9808a4a112790
  - License: GPL-3.0.
  - `device_config.h`: https://github.com/bitaxeorg/ESP-Miner/blob/d3dbcc51d11d33b7579baac8c5b9808a4a112790/main/device_config.h
  - The reviewed baseline exposes BM1397, BM1366, BM1368, and BM1370 ASIC drivers. It does not expose BM1362 or BM1398 drivers.
  - Its current newer-ASIC implementations and UART17/18 convention are starting points, not full-hashboard profiles.
- ESP-Miner S19 XP investigation: https://github.com/bitaxeorg/ESP-Miner/issues/248
  - Records one 110-chip BM1366 S19 XP example and useful initialization discussion. Treat it as one board variant, not a universal count.
- DCENT_OS platform notes: https://github.com/DCentralTech/DCENT_OS/blob/main/DCENT_OS_Antminer/docs/PLATFORMS.md
  - Used to associate established Antminer families with BM1398, BM1362, BM1366, BM1368, and BM1370 generations. Family labels span revisions, so exact board identity still controls.
- DCENT_OS S21 BM1368 profile: https://github.com/DCentralTech/DCENT_OS/blob/main/DCENT_OS_Antminer/dcentrald/dcentrald-silicon-profiles/src/bm1368.rs
  - Records a 108-chip, three-chain S21 profile, 3.125 Mbaud Bitmain operation, and a NoPIC warning: GPIO-resetting the chain can kill the TAS5782M DAC voltage. Rev A.1 therefore has an independent reset output-enable and keeps it disabled for S21 NoPIC.
- Third-party current model catalog: https://github.com/molepool/GMiner-Molepool-Asic-Release
  - Used only as variant/count evidence for exact-profile planning: examples include BM1366 S19 XP at 70/99/110 chips, S19k Pro at 77, BM1368 S21 at 108, and BM1370 S21 variants at 55/65/91.
  - This is not silicon-vendor documentation and does not establish a safe voltage, frequency, reset sequence, or connector rating.

## Primary component and layout sources

- Espressif ESP32-S3-WROOM-1 / WROOM-1U module datasheet: https://www.espressif.com/sites/default/files/documentation/esp32-s3-wroom-1_wroom-1u_datasheet_en.pdf
  - Module land pattern, 3.7 mm center pad and via array, antenna-end orientation, and antenna keepout used for the project-local footprint.
- Espressif ESP32-S3 PCB layout guidance: https://docs.espressif.com/projects/esp-hardware-design-guidelines/en/latest/esp32s3/pcb-layout-design.html
  - Board-edge antenna placement, 15 mm antenna keepout, continuous USB reference plane, and 90 Ω ±10% USB differential routing.
- Microchip EMC2301/2/3/5 datasheet: https://ww1.microchip.com/downloads/aemDocuments/documents/MSLD/ProductDocuments/DataSheets/EMC2301-2-3-5-Data-Sheet-DS20006532A.pdf
  - Four-wire fan support, PWM output configuration, tach measurement, startup strap behavior, and electrical limits.
- Diodes Inc. AP64501 datasheet, DS41980 Rev. 5-2: https://www.diodes.com/datasheet/download/AP64501.pdf
  - 3.8–40 V, 5 A synchronous buck candidate for the low-current logic rail. Its SO-8EP pin map, feedback equation, soft-start recommendation, compensation network, magnetics, output capacitance, and thermal behavior control the Rev A.1 implementation.
- TI TPS22917 datasheet, SLVSDW8B: https://www.ti.com/lit/gpn/TPS22917
  - Gated pin-16 3.3 V supply with reverse-current blocking; pin 4 is CT, pin 5 is QOD, and pin 6 is switched VOUT.
- TI TMUX1511 datasheet, SCDS390B: https://www.ti.com/lit/gpn/TMUX1511
  - Four-channel bidirectional switch with powered-off protection to 3.6 V, fail-safe select inputs, and internal select pulldowns. Rev A.1 powers it from `HB_3V3`, uses two channels for SCL/SDA, and adds an external enable pulldown.
- TI SN74AXC4T774 datasheet, SCES898C: https://www.ti.com/lit/gpn/SN74AXC4T774
- TI SN74LVC1G125: https://www.ti.com/product/SN74LVC1G125
- TI TPD4E05U06 datasheet/package drawing, SLVSBO7O: https://www.ti.com/lit/gpn/TPD4E05U06
  - DQA0010A signal lands, enlarged ground lands, pin numbering, and NC pins used for the cable-ESD footprint.
- ST USBLC6-2SC6: https://www.st.com/en/protections-and-emi-filters/usblc6-2.html
- Diodes Inc. DMP3013SFV datasheet: https://www.diodes.com/assets/Datasheets/DMP3013SFV.pdf
  - PowerDI3333-8 package pins 1–3 are source, pin 4 is gate, and pins 5–8 are drain. The reverse-input topology must be checked against that physical package map and diode-mode tested before fabrication.
- onsemi BZX84C12LT1G product/datasheet: https://www.onsemi.com/products/discrete-power-modules/zener-diodes/bzx84c12l
  - The SOT-23 map is pin 1 anode, pin 2 NC, pin 3 cathode. Rev A.1 uses it from the P-FET gate to protected `FAN_12V`; the 250 mW rating and clamp current need calculation and transient verification.
- Bitmain fan overview: https://support.bitmain.com/hc/en-us/articles/4402395808409-General-knowledge-and-Recurring-problem-about-Fan
  - General evidence that S19-family fans are four-wire 12 V units; the exact fan label/datasheet controls current, connector, pulses/revolution, and speed limits.
- Molex 0455580003 sales drawing SD-45558-001: https://www.molex.com/content/dam/molex/molex-dot-com/products/automated/en-us/salesdrawingpdf/455/45558/455580003_sd.pdf
  - J1 contact pitch, hole diameters, retention pegs, and circuit-1 orientation.
- Molex 0353180420 sales drawing SD-35318: https://www.molex.com/content/dam/molex/molex-dot-com/products/automated/en-us/salesdrawingpdf/353/35318/353180420_sd.pdf
  - J2–J5 unequal row/column pitch, hole diameters, and circuit numbering.
- GCT USB4105 drawing: https://gct.co/files/drawings/usb4105.pdf
- KiCad 8.0.9 USB4105 footprint: https://gitlab.com/kicad/libraries/kicad-footprints/-/blob/8.0.9/Connector_USB.pretty/USB_C_Receptacle_GCT_USB4105-xx-A_16P_TopMnt_Horizontal.kicad_mod
  - Drawing-derived USB-C signal lands, locating pegs, shell stakes, courtyard, and board-edge datum. KiCad footprint-library material is distributed under CC BY-SA 4.0; any vendored copy remains under that license.

## JLCPCB/LCSC references

- JLCPCB KiCad BOM/CPL export guide: https://jlcpcb.com/help/article/how-to-generate-the-bom-and-centroid-file-from-kicad
- JLCPCB BOM/CPL matching guidance: https://jlcpcb.com/help/article/common-bom-and-cpl-matching-issues-and-explanations
- Candidate LCSC pages:
  - ESP32-S3-WROOM-1-N16R8: https://www.lcsc.com/product-detail/C2913202.html
  - AP64501SP-13: https://www.lcsc.com/product-detail/C2071517.html
  - EMC2305-1-AP-TR: https://www.lcsc.com/product-detail/C621415.html
  - TMUX1511PWR: https://www.lcsc.com/product-image/C2866750.html
  - BZX84C12LT1G: https://www.lcsc.com/product-detail/C82475.html
  - USBLC6-2SC6: https://www.lcsc.com/product-detail/C7519.html
  - TPS22917DBVR: https://www.lcsc.com/product-detail/C2681320.html

These are sourcing candidates, not a frozen AVL. Confirm package, lifecycle, stock, JLC basic/extended status, substitutions, voltage ratings, and thermal limits at quotation time. Provisional TVS, connectors, power diodes, magnetics, fan-current protection, and reset-buffer ordering codes intentionally remain TBD in the engineering BOM.

## Clean-room and licensing boundary

This package records public interface facts and new engineering decisions. It intentionally contains no copied KiCad schematic, PCB, Gerber, or custom footprint file from the unlicensed aditBoard or AntHat repositories. If a later implementation copies CERN-OHL-S-2.0-covered Naja hardware or incorporates GPL-3.0-covered ESP-Miner code, distribute the required corresponding source and notices under those licenses.

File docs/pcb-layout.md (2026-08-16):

# PCB floorplan and routing brief

## Board and stack-up

- Outline: 100.0 × 70.0 mm, 1.6 mm finished thickness.
- Four copper layers: L1 signals/power, L2 uninterrupted GND, L3 quiet logic power with fan-rail exclusions, and L4 signals/power.
- Copper: request 2 oz outer layers if supported by the selected JLC four-layer stack; 1 oz inner layers is acceptable. Recalculate fan-current temperature rise after the stack is fixed.
- Finish: ENIG is preferred for the EMC2305 exposed-pad QFN and prototype rework; lead-free HASL is acceptable after assembly-yield review.
- Prototype rules: begin at 0.15/0.15 mm track/space and 0.30 mm finished drill in a 0.60 mm via, unless the selected JLC capability is more conservative.
- Mounting: four M3 holes at (4,4), (96,4), (4,66), and (96,66) mm. Set plated/NPTH and copper clearance to the enclosure/chassis strategy.

The intended component placement is recorded in `pcb/placement.csv` and illustrated in `pcb/floorplan.svg`.

## Functional zones

| Zone | Approximate area | Rules |
|---|---|---|
| Four fan connectors and FAN_12V bus | y = 0–16 mm | Short, wide L1/L4 pours; dense stitching; no sensitive traces |
| J1 regulated 12 V fan input | x = 82–100, y = 10–32 mm | High-current connector, Q5/Q6 reverse-polarity FETs, and TVS coordinated with the upstream external fuse; multiple current-transfer vias and thermal copper |
| Fan controller and safe sinks | x = 42–72, y = 17–32 mm | Quiet tach reference; PWM NMOS devices close to fan fan-out |
| Logic buck | x = 74–96, y = 24–40 mm | Tight switch loop; keep SW copper small and away from antenna |
| Hashboard connector/interface | x = 0–38, y = 22–52 mm | J10 at edge; ESD first; gated 3.3 V, UART/I²C and independent RESET |
| J6 logic input and expansion | x = 0–40, y = 54–68 mm | Low-current 12–15 V input; separated from cable I/O; no PSU interface |
| ESP and USB | x = 62–100, y = 42–70 mm | Module antenna at bottom edge; 15 mm keepout |

## Placement order

1. Fix J1, J2–J6, J10, and J30 from manufacturer drawings and real mating plugs.
2. Put TVS/ESD devices between every external cable connector and the first active device.
3. Place AP64501, inductor, input/output capacitors, bootstrap, and feedback as one compact datasheet-derived cell. Keep FB away from SW.
4. Keep the protected J6 path, USB path, and optional JP1/diode fan-to-logic path distinct until the logic-power OR node.
5. Place EMC2305 and its decoupler between the fan signal routes but outside the fan motor-current return path.
6. Place U5, U6, U7, and U12 behind J10 protection. Keep U12 RESET output-enable independent from U6 UART enable.
7. Place the ESP32-S3 module at the bottom edge with the antenna projecting over or immediately adjacent to the edge.
8. Route USB first, then UART/RESET, I²C/tach, service nets, and finally fan power. Review return current in startup, stall, and fault states.

## Critical routing constraints

### USB and ESP antenna

- Solve D+/D− for 90 Ω differential, ±10%, using the selected JLC stack-up rather than a hard-coded width.
- Match D+/D− within 0.5 mm, use the same via count, avoid stubs, and maintain continuous L2 GND.
- Put ESD next to J30 and the 22–33 Ω resistors next to the ESP.
- Keep the module antenna at the board edge. No copper, planes, vias, traces, components, fasteners, cables, or enclosure metal within its 15 mm keepout.
- Do not route the fan bus, J6 input, or buck switch node behind the antenna.

### Hashboard signals

- Route TX/RX as single-ended 3.3 V CMOS, not as a differential pair.
- Keep TX/RX/RESET short and over solid ground. Put each 33 Ω source/damping resistor next to its driver/translator.
- Route RESET from U12 independently; do not merge its enable with the UART translator enable.
- Keep hashboard I²C together over ground and away from fan PWM edges.
- Put U5/TPS22917 close to J10 pin 16 and provide a local HB_3V3 test point.
- Stitch ground beside J10 pins 1, 2, 9, 10, 13, and 14 and beside protection-array returns.
- Leave pins 17 and 18 copper-free except for labeled no-connect pads.

### Fan motor power

- J1 accepts regulated 12 V only. J6 is the 12–15 V logic input; do not merge their upstream nets.
- Reserve at least a 12–14 mm board-edge band for FAN_12V and ground distribution.
- Use both outer layers and via stitching at 1.5–2.0 mm pitch around current-transfer necks, with multiple via rows at J1 and each fan branch.
- Treat every connector pad, reverse-polarity FET, neck, pour, and layer transition as part of the board current path, and include the upstream external fuse and wiring in the system review. A wide pour cannot rescue an undersized terminal or hot FET.
- Calculate simultaneous startup/stall current and temperature rise from the actual AntHat fans. The provisional design target is 12 A total, not a guaranteed rating.
- Route tach and PWM alongside quiet ground and never through a motor-return bottleneck.

### Logic power

- Keep the protected `FAN_12V`→JP1/D2, J6→D1, and USB→D3 paths visually and electrically separable before `LOGIC_IN`.
- JP1 must be inaccessible to accidental closure or carry an unmistakable `12V ONLY` silkscreen warning.
- Choose OR devices for reverse isolation across all unpowered-source combinations. Verify USB cannot backfeed J1/J6 and 12–15 V cannot reach VBUS.
- Minimize the buck high-di/dt loop: input ceramic → U3 VIN/PGND → switch → U3 PGND → input ceramic.
- Keep SW only large enough to connect U3 and L1. Place output capacitors immediately after L1 and route FB from the output-capacitor sense point away from SW.

## Suggested net classes

| Class | Nets | Start rule | Finalization |
|---|---|---|---|
| USB_DIFF | USB_DP, USB_DN | Solver-derived width/spacing | JLC stack and impedance review |
| FAN_PWR | FAN_12V, FAN_GND | L1/L4 pours | IPC-2152 plus prototype thermography |
| LOGIC_INPUT | VIN_LOGIC_12_15, LOGIC_IN | ≥0.75 mm where practical | OR-device/regulator current and surge analysis |
| LOGIC_PWR | 3V3, HB_3V3 | ≥0.50 mm where practical | Regulator/load-current calculation |
| HB_UART | HB_TX, HB_RX, HB_RESET | 0.20–0.25 mm | Scope edge quality at each profile baud |
| I2C_TACH | SDA/SCL/tach/alert | 0.20–0.25 mm | Rise-time check with final cable and pull-ups |
| GPIO | Remaining digital | 0.20 mm | Standard DRC |

## Assembly notes for JLCPCB

- Keep manufacturer MPN and LCSC code in separate fields. Footprint compatibility alone does not approve a substitute.
- Use explicit `DNP` fields for the optional fan pull-up rail, profile straps, and JP1; do not rely on omitted BOM rows.
- High-current and shrouded THT connectors may need hand installation or JLC wave/selective solder service.
- Inspect every rotation and side in JLC's assembly preview. Right-angle and bottom-inserted THT connectors need manual orientation review.
- Add labeled test pads for FAN_12V, VIN_LOGIC_12_15, LOGIC_IN, USB_VBUS, 3V3, HB_3V3, both I²C buses, TX, RX, RESET, RESET_OE_N, PLUG, and all tach/PWM channels.

## Fault-containment boundary

Rev A.1 has no PSU connection, so it cannot guarantee removal of the hashboard core supply. On a fault it can stop work submission, request the profile's hashboard-local voltage-off command when supported, disable cable interfaces, keep RESET behavior profile-safe, and release every fan PWM input for full speed. If local shutdown does not succeed, external removal of hashboard power is required. Placement, labels, and documentation must not imply a hard power-cut function that the PCB does not contain.

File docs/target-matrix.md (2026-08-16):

# S19/S21 target matrix

This matrix separates **connector compatibility** from **firmware readiness**. Rev A.1 uses one common 18-position/16-used, 3.3 V cable interface for all rows. A board is not allowed to mine until its exact SKU/profile defines chip family, chip count, address stride, UART sequence, reset behavior, and I²C voltage/temperature control.

| Miner family / example | ASIC | Typical chips per board | Current ESP-Miner chip driver | Rev A.1 status |
|---|---|---:|---|---|
| Legacy S19 / S19 Pro revisions | BM1398 | SKU-dependent | No | Connector-compatible; new driver required |
| S19 / S19 Pro / S19j-class BM1362 revisions | BM1362 | variants include 84, 88, 108, 120, or 126 | No | Connector-compatible; new driver required; model name alone is insufficient |
| S19 XP / S19j XP | BM1366 | variants include 70, 99, or 110 | Yes | Candidate after exact-SKU profile and full-chain tests |
| S19k Pro | BM1366 | commonly 77 | Yes | Candidate after exact-SKU profile and full-chain tests |
| S21 | BM1368 | commonly 108 | Yes | Preferred first S21 target; NoPIC-aware path required |
| S21 Pro | BM1370 | commonly 65 | Yes | Candidate after exact-SKU profile and reset/voltage proof |
| S21 XP | BM1370 | commonly 91 | Yes | Candidate after exact-SKU profile and reset/voltage proof |
| S21+ | BM1370 | commonly 55 | Yes | Candidate after exact-SKU profile and reset/voltage proof |

Counts are catalog/firmware evidence, not a substitute for reading the exact hashboard label/EEPROM, confirming its ASIC ID, and confirming enumeration. The same family name can span silicon and board revisions. Hydro, immersion, repair-class, and regional variants often use different counts and are outside the first-article scope.

## Recommended bring-up order

1. **S21 / BM1368 / 108 chips** — current ESP-Miner already has the chip driver, public full-board work identifies a 108-chip chain, and the main special case is explicit: do not apply legacy GPIO-reset behavior to the NoPIC/DAC power path.
2. **S19 XP / BM1366 / exact labeled count** — current chip driver exists, but the family has multiple chain counts and board revisions.
3. **BM1370 S21 variants** — driver exists, but use a distinct profile per exact SKU/count.
4. **BM1362 and BM1398 S19 variants** — hardware connector may be used, but firmware driver work comes first.

## Profile record required in firmware

Each supported hashboard must have an immutable profile containing:

- exact model/SKU string and accepted aliases;
- ASIC chip ID and expected response length;
- exact chip count and address stride;
- reset policy: `legacy_active_low`, `no_gpio_reset`, or another proven sequence;
- initial and operating UART baud plus register sequence;
- I²C devices, addresses, and pull-up assumptions;
- voltage enable/set/readback method, if present on the board;
- temperature sensor type, location, conversion, and limits;
- conservative frequency/voltage starting point;
- fan count and minimum airflow interlock; and
- tested shutdown and recovery order.

Runtime chip-ID detection may choose a driver, but it must not invent a chip count or power/reset policy. Ambiguous or unknown SKUs remain in management/diagnostic mode.

## Evidence notes

- Current ESP-Miner's ASIC enum and drivers include BM1366, BM1368, and BM1370, but not BM1362 or BM1398.
- ESP-Miner issue #248 records an S19 XP example with 110 BM1366 chips.
- DCENT_OS's S21 silicon profile records 108 BM1368 chips, 3.125 Mbaud Bitmain operation, and a NoPIC warning against legacy GPIO reset.
- Public third-party hashboard catalogs list multiple different counts within both S19 XP and S21-derived product names; exact SKU identity is therefore a required safety input.

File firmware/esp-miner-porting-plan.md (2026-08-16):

# ESP-Miner multi-profile porting plan — S19/S21

Baseline reviewed: `bitaxeorg/ESP-Miner` commit `d3dbcc51d11d33b7579baac8c5b9808a4a112790` (GPL-3.0). Rev A.1 should be added as a new board family with an explicit hashboard-profile layer; it must not masquerade as an existing Bitaxe device.

## Driver readiness

| Hashboard family | ASIC | Driver in reviewed ESP-Miner baseline | Initial work |
|---|---|---|---|
| Legacy S19 / S19 Pro revisions | BM1398 | No | Implement and validate a new ASIC driver before mining |
| S19 / S19 Pro / S19j-class BM1362 revisions | BM1362 | No | Implement and validate a new ASIC driver before mining |
| S19 XP / S19j XP / S19k Pro | BM1366 | Yes | Add one immutable profile per exact SKU/chip count and validate a full chain |
| S21 | BM1368 | Yes | Add the 108-chip profile and a NoPIC startup path that never drives RESET |
| S21 Pro / S21 XP / S21+ | BM1370 | Yes | Add separate profiles for their different chip counts and control paths |

The current enum/driver list is visible in ESP-Miner's [`device_config.h`](https://github.com/bitaxeorg/ESP-Miner/blob/d3dbcc51d11d33b7579baac8c5b9808a4a112790/main/device_config.h). An [ESP-Miner S19 XP issue](https://github.com/bitaxeorg/ESP-Miner/issues/248) provides evidence for one 110-chip BM1366 example, not a universal S19 XP count.

## Board GPIO contract

| Function | GPIO | Required firmware behavior |
|---|---:|---|
| Hashboard RESET command | 1 | Drive only through the independently gated reset buffer and only for profiles that explicitly permit it |
| `HB_RESET_OE_N` | 4 | Pull-up makes reset high-impedance; keep high for every `no_gpio_reset` profile |
| Expansion/test | 5, 6 | Leave high-impedance in Rev A.1 production firmware |
| Hashboard UART/PLUG `/OE` | 7 | Active low; external pull-up; enable only after profile selection |
| `FAN_ARM` | 8 | Active high; external pulldown; assert only after EMC2305 configuration and readback |
| Hashboard I2C switch enable | 9 | Active high; external pulldown; keep low before every `HB_3V3` ramp and until the switched rail is stable |
| Hashboard pin-16 3.3 V enable | 10 | Active high; external pulldown |
| Rail monitor | 11 | ADC; require calibrated, plausible values before mining |
| Hashboard `PLUG` | 12 | Debounce and interpret through the exact-board profile |
| EMC2305 ALERT | 13 | Interrupt plus periodic status polling |
| Hashboard SDA/SCL | 14 / 21 | Dedicated hardware I2C controller |
| ASIC UART TX/RX | 17 / 18 | UART1, 8-N-1; matches the reviewed ESP-Miner pin convention |
| Local EMC2305 SDA/SCL | 47 / 48 | Dedicated hardware I2C controller |

All enable GPIOs must be configured to their safe inactive state before any driver probes a bus.

## Profile schema

Create a compile-time table or signed configuration whose records cannot silently fall back to another model. Each profile needs:

- stable profile ID plus exact accepted label/EEPROM identifiers;
- ASIC model, expected response signature, exact chip count, address stride, and domain topology;
- reset policy such as `legacy_active_low` or `no_gpio_reset`, with timings only where measured;
- initial UART rate, register/baud-change sequence, operating UART rate, and verification transaction;
- I2C device addresses and a proven board-local voltage enable/set/readback/shutdown sequence;
- temperature sensor model, conversion, location, plausible range, stale limit, warning and trip limits;
- conservative starting voltage/frequency and bounded ramp steps;
- required fan count, pulses/revolution, minimum plausible RPM, spin-up time, and tach-stale limit; and
- tested startup, fault, cooldown, and recovery ordering.

Runtime ASIC-ID probing may corroborate a configured profile. It must not guess chip count, reset behavior, voltage protocol, or thermal limits from a family name. A missing, conflicting, or ambiguous identity leaves the unit in diagnostic mode.

## Work packages

1. Add an `chainaxe_reva1` board definition with the GPIO contract above and separate `i2c_local` and `i2c_hashboard` buses.
2. Introduce `hashboard_profile_t` and require an exact profile before any cable driver or pin-16 power is enabled.
3. Wrap the existing ASIC drivers behind profile operations for discover, address, set-baud, configure, submit work, read result, and stop.
4. Add an EMC2305 driver with output-type/polarity setup, four PWM/tach channels, tach-age tracking, ALERT decoding, and register readback before `FAN_ARM`.
5. Add `hashboard_power_ops` for board-local I2C `probe`, `enable`, `set_voltage`, `read_status`, `read_temperatures`, and `shutdown`. Do not emulate absent PSU control.
6. Make one high-priority safety task the sole owner of the hashboard OEs, reset OE, pin-16 enable, `FAN_ARM`, and `mining_allowed`.
7. Harden UART RX into a streaming parser that resynchronizes after partial/corrupt frames, validates length/CRC, and publishes error counters. Full-hashboard cables need stricter fault accounting than local Bitaxe traces.
8. Expose profile ID, detected ID/count, state, latched fault, fan RPM/age, temperature age, local-voltage status, UART errors, and recovery count through the UI/API.
9. Preserve ESP-Miner's GPL-3.0 notices and corresponding-source obligations in every distributed firmware image.

## Safety state machine

| State | Required actions and transition |
|---|---|
| `SAFE_BOOT` | Set `FAN_ARM=0`; pin-16 off; UART/PLUG and I2C switches disabled; reset buffer disabled; no jobs. Fan PWM drains float so compatible fans request full speed. |
| `LOCAL_CHECK` | Initialize local I2C, configure EMC2305 for the proven output polarity/mode, command 100%, read registers back, then assert `FAN_ARM`. Require plausible fresh tach from every required fan after spin-up. |
| `PROFILE_SELECT` | Require a configured exact SKU/profile, stable plug state, matching identity evidence, and no latched fault. Unknown or conflicting boards stop here. |
| `HB_IO_START` | Hold `HB_I2C_EN=0`; enable the gated pin-16 3.3 V rail; wait and verify it; then enable the TMUX1511 I2C paths and UART/PLUG paths in the selected profile's order. Reset remains high-impedance unless the profile later requests it. |
| `LOCAL_POWER_CHECK` | Probe the profile's hashboard-local controller/sensors; confirm safe voltage and fresh temperature data. If a local enable command is required, use only the proven per-profile sequence. |
| `ASIC_START` | For a legacy-reset profile, briefly enable the reset buffer and run its measured reset sequence. For S21 NoPIC, never enable the reset buffer and proceed with the bus-only initialization sequence. |
| `ENUMERATE` | Start at the profile's initial baud (normally 115200), enumerate valid responses, and require the exact expected count/IDs before address or clock changes. |
| `CONFIGURE` | Assign addresses, apply the exact ASIC register order, transmit the baud-change command at the old rate, wait for TX completion, switch the ESP UART, and prove the new link before ramping. |
| `MINING` | Accept work only while fan, temperature, plug, rail, identity/count, local-control, and UART-health interlocks remain current and valid. Ramp from a conservative voltage/frequency in bounded steps. |
| `FAULT_LATCHED` | Stop jobs; execute the tested board-local voltage-off/shutdown command if available; deassert the I2C switch before turning off `HB_3V3`; disable other cable paths in the profile-defined safe order; leave S21 reset untouched; release `FAN_ARM` for full-speed cooling; latch cause. |
| `RECOVERY` | Allow at most one conservative retry only for explicitly recoverable faults after a complete cooldown and healthy telemetry interval. Repeated or shutdown-path faults require manual acknowledgement and external power removal. |

An ESP reset or watchdog event must return to `SAFE_BOOT` through physical pulls before application code runs.

## Reset and UART rules

The S21/BM1368 path is a first-class special case, not a timing variation. The public [DCENT_OS S21 profile](https://github.com/DCentralTech/DCENT_OS/blob/main/DCENT_OS_Antminer/dcentrald/dcentrald-silicon-profiles/src/bm1368.rs) identifies a NoPIC design and warns that GPIO-resetting the chains kills the TAS5782M DAC voltage. Therefore an S21 profile keeps GPIO4 high and the reset buffer high-impedance from boot through fault handling.

Bring-up starts at 115200 unless an exact profile proves otherwise. The reviewed ESP-Miner drivers commonly transition newer ASICs to 1 Mbaud, while the public Bitmain-derived S21 profile records 3.125 Mbaud operation. Treat operating baud as profile data: send the ASIC baud command while the ESP is still at the old rate, wait for TX completion, switch the local UART, and validate register reads before accepting work. Do not select the faster number merely because the chip family can support it.

## Fault policy without PSU control

Rev A.1 has no means to disconnect the external hashboard core-power bus. Its strongest local response is to stop work, send a previously validated hashboard-local I2C voltage-off/shutdown command, disable cable interfaces where doing so is safe, and force fans to their fail-safe full-speed condition. If temperature rises, the local command NACKs, rail readback remains unsafe, or the board profile has no proven shutdown operation, firmware must display **EXTERNAL POWER REMOVAL REQUIRED** and remain latched. Documentation and UI must never describe this as a guaranteed hard shutdown.

Other mandatory trips:

- missing/stale/implausible fan tach, EMC2305 ALERT, or local-I2C failure;
- stale/invalid temperature data or a profile-specific overtemperature;
- plug removal, hashboard-I2C failure, unexpected chip count/ID, CRC/framing storm, or failed baud verification;
- brownout or watchdog reset; and
- an attempted profile change while any hashboard interface is enabled.

Network/pool loss is not a reason to disable cooling. Stop issuing work and move to the profile's safe idle state while telemetry continues.

## Validation sequence

### Host tests

- Golden command/response/CRC vectors for every supported ASIC driver.
- Exact address list and count for every profile.
- State-transition tests for every timeout, reset policy, and fault.
- Parser fuzzing with partial, concatenated, corrupted, and shifted frames.
- EMC2305 polarity, tach/RPM conversion, stale-age, ALERT, `FAN_ARM`, and watchdog tests.
- Assert in tests that `no_gpio_reset` profiles can never lower GPIO4 or drive GPIO1 onto the cable.

### Controller-only HIL

- Record all enable pins during power-on, flashing, brownout, watchdog, and software reset.
- Confirm USB cannot backfeed J1, J6, fan motor power, or J10 pin 16.
- Exercise four real fans; unplug and stall each independently; verify floating PWM produces full speed.
- Verify J1 only receives regulated 12 V and J6 operates over 12–15 V.
- Short each I2C line through a safe resistor and prove mining cannot become allowed.

### Unpowered / locally powered hashboard

- Confirm connector orientation, common ground, 3.3 V signal levels, PLUG polarity, I2C devices, and pin-16 current with a scope/current limit.
- On S21, prove RESET remains high-impedance during every boot and fault transition.
- Validate the board-local voltage/temperature controller and safe shutdown command without enabling mining.

### Low-power full-chain test

- Enumerate the exact profile count at 115200 on at least 100 cold boots.
- Validate address assignment and the selected operating rate with no persistent CRC/framing faults.
- Start at the profile's conservative voltage/frequency; compare current, temperatures, and response rate with known-good controller behavior.

### Mining and fault injection

- Submit known jobs and verify accepted nonces/shares.
- Inject fan stall, cable removal, stale temperature, I2C NACK, UART corruption, local-voltage-control failure, brownout, and ESP watchdog.
- Verify prompt job stop, the local shutdown request when supported, full-speed fan fallback, latched UI warning, and the explicit external-disconnect requirement when core power remains.
- Complete a 24-hour conservative soak before any ramp increase; log UART errors, minimum fan RPM, temperatures, resets, local rail state, and accepted/rejected shares.

## Release blockers

- Exact first hashboard SKU/revision, verified chip count/domain map, and readable identity method.
- Exact reset policy and proof that S21 NoPIC never sees a driven reset.
- Exact board-local voltage, temperature, enable, readback, and shutdown protocol.
- Tested initial/operating baud and complete initialization register order.
- Exact fans, current/inrush, pulses/revolution, minimum safe RPM, and connector orientation.
- Sensor calibration and conservative voltage/frequency/temperature envelope.
- Clear operator procedure or independent hardware protection for removal of external core power.

Until these are closed, firmware remains a supervised bench/enumeration build and must not permit unattended mining.

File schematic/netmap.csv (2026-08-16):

Block | ESP32-S3 GPIO | ESP net | Intermediate | External net | Default safe state | Rev A.1 population
Hashboard UART TX | 17 | HB_TX_3V3 | SN74AXC4T774 + 33R | HB_TX | U6 disabled; connector-side optional DNP bias | POPULATE
Hashboard UART RX | 18 | HB_RX_3V3 | SN74AXC4T774 + optional 33R | HB_RX | U6 disabled | POPULATE
Hashboard plug detect | 12 | HB_PLUG_3V3 | SN74AXC4T774 | HB_PLUG | U6 disabled; ESP-side weak pulldown | POPULATE
Hashboard translator enable | 7 | HB_XLAT_OE_N | SN74AXC4T774 /OE | — | 100k pullup disables U6 | POPULATE
Hashboard reset command | 1 | HB_RESET_CMD | SN74LVC1G125 + 33R | HB_RESET | Reset output high impedance; connector-side bias pads DNP | POPULATE
Hashboard reset enable | 4 | HB_RESET_OE_N | SN74LVC1G125 /OE | — | 10k pullup disables U12; default S21 assembly also leaves RESET_ENABLE_LINK open and firmware never enables | POPULATE
Hashboard logic power | 10 | HB_IO_PWR_EN | TPS22917 ON | HB_3V3 / J10.16 | 100k pulldown keeps switch off | POPULATE
Hashboard I2C data | 14 | HB_SDA_3V3 | TMUX1511 channel 2 | HB_SDA | U7 powered from HB_3V3; powered-off isolation; pullups split by domain | POPULATE
Hashboard I2C clock | 21 | HB_SCL_3V3 | TMUX1511 channel 1 | HB_SCL | U7 powered from HB_3V3; powered-off isolation; pullups split by domain | POPULATE
Hashboard I2C enable | 9 | HB_I2C_EN | TMUX1511 SEL1 + SEL2 | — | 100k pulldown disables both used channels; unused selects grounded | POPULATE
Fan I2C data | 47 | FAN_SDA | 4.7k pullup | EMC2305 SMDATA | High via pullup | POPULATE
Fan I2C clock | 48 | FAN_SCL | 4.7k pullup | EMC2305 SMCLK | High via pullup | POPULATE
Fan alert | 13 | FAN_ALERT_N | 4.7k pullup | EMC2305 ALERT# | High/inactive | POPULATE
Fan arm | 8 | FAN_ARM | SN74LVC126 enables | — | 100k pulldown disables U8; PWM floats so compatible fans default full speed | POPULATE
Rail monitor | 11 | RAIL_MON | Stuff-option divider + RC | FAN_12V or LOGIC_IN monitor | ADC input low/defined | PROVISIONAL
Expansion pad 1 | 5 | EXP_GPIO5 | Test pad | — | Input/high impedance | POPULATE PAD
Expansion pad 2 | 6 | EXP_GPIO6 | Test pad | — | Input/high impedance | POPULATE PAD
Native USB D- | 19 | USB_DN | ESD + 22R | USB-C D- | USB disconnected | POPULATE
Native USB D+ | 20 | USB_DP | ESD + 22R | USB-C D+ | USB disconnected | POPULATE
Boot strap | 0 | BOOT_N | Button to GND | — | External pullup/default high | POPULATE
Debug TX | 43 | DBG_TX | Test pad/header | — | Idle high | OPTIONAL
Debug RX | 44 | DBG_RX | Test pad/header | — | Weak pullup/unused | OPTIONAL

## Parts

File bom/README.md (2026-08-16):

# BOM usage — ChainAxe Rev A.1

`chainaxe-reva-bom.csv` is the engineering BOM for the S19/S21-oriented controller. It deliberately retains TBD, DNP, `SELECT_BEFORE_RELEASE`, and `STOP_ORDER` rows so unknown connector, power, and protection choices cannot be mistaken for released production data. Rev A.1 contains no PSU connector or PSU-control circuitry.

`chainaxe-reva-engineering-bom.xlsx` is the review-friendly workbook. It contains a status summary, the complete engineering BOM, and the current JLC upload table. The CSV files remain the source for automation and JLCPCB import.

`jlcpcb-bom-template.csv` demonstrates JLCPCB's four useful upload columns for fitted SMT candidates whose current LCSC codes are recorded. Its designators and footprint strings are synchronized to the frozen Rev A.1 schematic, but it is **not upload-ready**: all provisional choices and quote-time availability still need review, and the file must be regenerated with the final PCB/CPL revision.

The template intentionally excludes DNP parts, bare-PCB test points, external parts, hand-installed connectors, exact-part TBDs, and every `STOP_ORDER` item. In particular, J30 is excluded until its vendored manufacturer-drawing footprint is verified by 1:1 print and real-part fit; SW1/SW2 are excluded because the prior MPN/LCSC pairing was not verified against the schematic footprint.

Status and population meanings:

- `EXACT_CANDIDATE`: the MPN/LCSC pairing is specific enough for schematic entry, but still requires quote-time identity, package, lifecycle, and stock checks.
- `PROVISIONAL`: a useful candidate whose electrical, thermal, footprint, or sourcing details still require validation.
- `TBD`: do not freeze the part, footprint, or purchase choice.
- `SELECT_BEFORE_RELEASE`: the function is required, but the exact part/value must be selected before fabrication release.
- `STOP_ORDER`: a known hard blocker; no fabrication or assembly upload is permitted until the row's note is resolved.
- `DNP`: footprint retained but unpopulated in the default Rev A.1 variant.
- `HAND_INSTALL`: not assumed to be available in JLC's standard SMT assembly flow.
- `PCB_FEATURE`: a schematic/PCB reference such as a bare-copper test pad, not a purchased or placed component.

Power-variant rule: J1 is a regulated 12 V high-current fan input. J6 is a low-current 12–15 V logic input. JP1 may be fitted only when J1 is verified to be regulated 12 V; it feeds the controller through D2 and does not make J1 tolerant of 15 V fans.

Before a JLC order:

1. Re-open every LCSC page and verify manufacturer, exact MPN, package, lifecycle, and stock.
2. Revalidate the J1 `0455580003` and J2–J5 `0353180420` candidates, then freeze J1, J2–J5, J6, and J10 from current manufacturer drawings and real mating-part fit checks.
3. Select and thermally validate Q5/Q6, D4/D5, AP64501 compensation/magnetics, input/output ceramics, bulk capacitors, and the external fan fuse from calculated and measured loads.
4. Export BOM and position/CPL files directly from the same annotated KiCad revision used for Gerbers.
5. Exclude every DNP row from the upload BOM while retaining DNP markings and assembly variants in source.
6. Inspect substitutions, rotations, board side, exposed pads, and pin 1 in JLC's assembly preview.
7. Hand-fit J1, J2–J5, J6, J10, and JP1 on the first articles unless an explicit THT assembly quote has been accepted.

U5, U6, and U7 are populated on Rev A.1 because J10 pin 16 and all signal domains are controller-side 3.3 V. U12 is a separate, normally disabled reset driver. Its 10 kΩ GPIO4 enable pull-up is mandatory. The series RESET link is DNP/open in the default S21-safe assembly and may be fitted with 33 Ω only for a validated legacy-reset target.

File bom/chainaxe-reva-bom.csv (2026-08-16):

Status | Designator | Qty | Function | Value | Manufacturer | MPN | Footprint | LCSC Part # | Assembly | Population | Notes
EXACT_CANDIDATE | U1 | 1 | MCU module | ESP32-S3-WROOM-1-N16R8 | Espressif | ESP32-S3-WROOM-1-N16R8 | ChainAxe:ESP32-S3-WROOM-1_v1.8 | C2913202 | SMT extended | POPULATE | Project-local footprint follows Espressif v1.8 land pattern with 3.7 mm center pad/vias and antenna keepout; verify metal-chassis strategy
PROVISIONAL | U2 | 1 | Four-channel fan controller | EMC2305 | Microchip | EMC2305-1-AP-TR | ChainAxe:EMC2305_QFN16_4x4_P0.65_EP2.2 | C621415 | SMT extended | POPULATE | AP-specific 2.2 mm exposed land with paste windowing and thermal vias; use channels 1-4; fifth channel NC
PROVISIONAL | U3 | 1 | 3.3 V synchronous buck | AP64501 | Diodes Incorporated | AP64501SP-13 | ChainAxe:AP64501_SO8EP | C2071517 | SMT extended | POPULATE | Project-local Diodes land/paste/thermal-via pattern; DS41980 Table 1 starting cell is implemented; validate loop stability, transients, and thermal margin
PROVISIONAL | L1 | 1 | Buck inductor | 3.3 uH | Bourns | SRP5030T-3R3M | Inductor_SMD:L_Bourns-SRP5030TA_5.7x5.2mm | C189931 | SMT extended | POPULATE | Recalculate saturation and RMS current for the final 3.3 V design
PROVISIONAL | U5 | 1 | Switched hashboard logic supply | 3.3 V 2 A load switch | Texas Instruments | TPS22917DBVR | Package_TO_SOT_SMD:SOT-23-6 | C2681320 | SMT extended | POPULATE | Controller sources J10 pin 16; R50 holds the switch off at reset
PROVISIONAL | U6 | 1 | Gated hashboard UART/PLUG interface | SN74AXC4T774 | Texas Instruments | SN74AXC4T774PWR | Package_SO:TSSOP-16_4.4x5mm_P0.65mm | C1849453 | SMT extended | POPULATE | Both domains are 3.3 V; directions and OE mapping are frozen in the schematic
EXACT_CANDIDATE | U7 | 1 | Powered-off-protected hashboard I2C switch | TMUX1511 | Texas Instruments | TMUX1511PWR | Package_SO:TSSOP-14_4.4x5mm_P0.65mm | C2866750 | SMT extended | POPULATE | VDD from switched HB_3V3; channels 1/2 carry SCL/SDA; R84 disables both used channels by default
EXACT_CANDIDATE | U8 | 1 | Four-channel active-high tri-state fan buffer | SN74LVC126A | Texas Instruments | SN74LVC126APWR | Package_SO:TSSOP-14_4.4x5mm_P0.65mm | C7815 | SMT extended | POPULATE | R105 leaves all 2N7002 sinks off; verify float-PWM full-speed behavior with the exact fan
EXACT_CANDIDATE | U12 | 1 | Independent gated hashboard reset buffer | SN74LVC1G125 | Texas Instruments | SN74LVC1G125DBVR | Package_TO_SOT_SMD:SOT-23-5 | C23654 | SMT extended | POPULATE | R89 is the mandatory 10k active-low OE pullup; default S21 assembly leaves R90 open/DNP
EXACT_CANDIDATE | Q1,Q2,Q3,Q4 | 4 | Fan open-drain PWM sinks | 2N7002 | Nexperia or approved | 2N7002 | Package_TO_SOT_SMD:SOT-23 | C8545 | SMT basic | POPULATE | R200/R203/R206/R209 are gate pulldowns; drain connects to each fan PWM line
PROVISIONAL | Q5,Q6 | 2 | Parallel high-side fan-input reverse-polarity FETs | -30 V P-channel | Diodes Incorporated | DMP3013SFV-7 | ChainAxe:PowerDI3333-8_DMP3013SFV | C264098 | SMT extended | SELECT_BEFORE_RELEASE | Use exact Diodes Type-UX mapping; validate paste, SOA, current sharing, Rds(on), copper, and simultaneous fan startup/stall thermals
EXACT_CANDIDATE | ZD1 | 1 | Fan-input MOSFET gate clamp | 12 V Zener | onsemi | BZX84C12LT1G | Package_TO_SOT_SMD:SOT-23 | C82475 | SMT extended | SELECT_BEFORE_RELEASE | Pin 1 anode to gate; pin 2 NC; pin 3 cathode to protected FAN_12V; validate dissipation and transients
EXACT_CANDIDATE | U9 | 1 | USB low-capacitance ESD | USBLC6-2SC6 | STMicroelectronics | USBLC6-2SC6 | Package_TO_SOT_SMD:SOT-23-6 | C7519 | SMT extended | POPULATE | Place immediately behind the USB receptacle
EXACT_CANDIDATE | U10,U11,U13 | 3 | Cable-side 3.3 V ESD array | TPD4E05U06 | Texas Instruments | TPD4E05U06DQAR | ChainAxe:TI_DQA0010A_USON10_2.5x1.0_P0.5 | C138714 | SMT extended | POPULATE | TI DQA0010A map and land: shunts 1/2/4/5; enlarged GND 3/8; NC 6/7/9/10; verify pin 1 at J10
PROVISIONAL | D1,D2,D3 | 3 | Logic-source OR Schottky | 1 A 40 V | Multiple | SS14 | Diode_SMD:D_SMA | TBD | SMT | POPULATE | D1 gives J6 reverse blocking; D2 is JP1-qualified FAN_12V; D3 is USB_VBUS; select exact MPN/LCSC and verify AP64501 headroom
PROVISIONAL | D4 | 1 | Protected fan-bus TVS | 13 V standoff starting point | Multiple | SMBJ13A | Diode_SMD:D_SMB | TBD | SMT | SELECT_BEFORE_RELEASE | Coordinate standoff and clamp energy with the exact 12 V fans and upstream fuse; J1 is not a 15 V fan input
PROVISIONAL | D5 | 1 | Logic-input bidirectional TVS | 18 V standoff starting point | Multiple | SMBJ18CA | Diode_SMD:D_SMB | TBD | SMT | SELECT_BEFORE_RELEASE | Bidirectional part at J6; verify pulse energy and clamping before release
PROVISIONAL | J30 | 1 | USB-C USB2 receptacle | USB4105-GF-A | Global Connector Technology | USB4105-GF-A | ChainAxe:USB4105-GF-A | C2988369 | SMT extended | STOP_ORDER | STOP-ORDER until first-article fit check: project-local footprint vendors the official KiCad 8.0.9/GCT geometry with all contacts, THT shell stakes, and NPTH locating pegs
PROVISIONAL | J10 | 1 | Bitmain hashboard data connector | 2x9 2.00 mm right-angle | HCTL | PM200-2-09-W-4.3 | ChainAxe:PM200-2-09-W-4.3_THT | C3012192 | THT/manual | HAND_INSTALL | 18 physical positions; pins 1-16 used and 17-18 NC; project-local drawing-derived footprint still needs mating-face orientation and real-cable fit checks
EXACT_CANDIDATE | J1 | 1 | High-current fan supply input | 2x3 keyed THT | Molex | 0455580003 | ChainAxe:0455580003_THT | C492365 | THT/manual | HAND_INSTALL | Regulated 12 V only; project-local footprint follows Molex SD-45558-001 contact and peg geometry; verify circuit-1 orientation and fit a real connector
TBD | J6 | 1 | Low-current controller supply input | 2-pin keyed 18-24 AWG | TBD | TBD | Connector_Molex:Molex_Micro-Fit_3.0_43650-0200_1x02_P3.00mm_Horizontal | TBD | THT/manual | STOP_ORDER | STOP-ORDER: accepts 12-15 V for logic only; current Micro-Fit footprint is a placeholder until an exact keyed connector and mate are selected
EXACT_CANDIDATE | J2,J3,J4,J5 | 4 | AntHat-style four-wire fan connectors | Keyed 2x2 nominal 4.2 mm pitch | Molex | 0353180420 | ChainAxe:0353180420_THT | C54909 | THT/manual | HAND_INSTALL | Silk G/12/T/P; project-local footprint follows Molex SD-35318 4.2 x 5.5 mm pattern; verify key, circuit view, and real fan harness
TBD | JP1 | 1 | Optional fan-to-logic feed | Open solder jumper | N/A | N/A | Jumper:SolderJumper-2_P1.3mm_Open_Pad1.0x1.5mm | N/A | Manual | DNP | Fit only when J1 is verified regulated 12 V; feeds FAN_12V through D2 and never bypasses the diode
TBD | SW1,SW2 | 2 | BOOT and RESET buttons | Momentary NO | TBD | TBD | Button_Switch_SMD:SW_SPST_CK_RS282G05A3 | TBD | SMT | STOP_ORDER | STOP-ORDER: schematic uses the CK RS282G05A3 footprint; prior CS1213AGF260/C5578986 pairing is not footprint-verified and is removed from the JLC template
EXACT_CANDIDATE | R60 | 1 | Fan-input reverse-protection gate resistor | 12k 1% | UNI-ROYAL | 0402WGF1202TCE | Resistor_SMD:R_0402_1005Metric | C25752 | SMT basic | SELECT_BEFORE_RELEASE | Q5/Q6 gate pull; validate with ZD1 and final FET topology
EXACT_CANDIDATE | R50,R80,R83,R84,R105,R106,R107,R108,R109,R200,R203,R206,R209 | 13 | Hardware safe-state pulls | 100k 1% | UNI-ROYAL | 0402WGF1003TCE | Resistor_SMD:R_0402_1005Metric | C25741 | SMT basic | POPULATE | U5 off; U6 off; PLUG defined; U7 off; fan arm off; R106-R109 define U8 inputs low until EMC2305 push-pull configuration; four fan gates off
PROVISIONAL | R70 | 1 | Rail-monitor divider top | 100k 1% | UNI-ROYAL | 0402WGF1003TCE | Resistor_SMD:R_0402_1005Metric | C25741 | SMT basic | POPULATE | With R71 and C70; validate ADC full-scale against the selected monitored rail
PROVISIONAL | R91,R92 | 2 | Optional hashboard reset bias pads | 100k starting value | UNI-ROYAL | 0402WGF1003TCE | Resistor_SMD:R_0402_1005Metric | C25741 | SMT basic | DNP | Mutually exclusive reset bias-up/down options; default S21-safe assembly leaves both open
EXACT_CANDIDATE | R89,R110,R111 | 3 | Reset-OE and MCU EN/BOOT pullups | 10k 1% | UNI-ROYAL | 0402WGF1002TCE | Resistor_SMD:R_0402_1005Metric | C25744 | SMT basic | POPULATE | R89 disables U12; R110 is ESP EN pullup; R111 is BOOT pullup
PROVISIONAL | R51 | 1 | Hashboard 3.3 V quick-output-discharge link | 100 ohm 1% | Multiple | TBD | Resistor_SMD:R_0402_1005Metric | TBD | SMT | POPULATE | VOUT to TPS22917 QOD; J10 pin 16 must never be externally driven
PROVISIONAL | R71 | 1 | Rail-monitor divider bottom | 27k 1% | Multiple | TBD | Resistor_SMD:R_0402_1005Metric | TBD | SMT | POPULATE | With R70 and C70; validate ADC scaling and source impedance
EXACT_CANDIDATE | R112,R113 | 2 | USB-C CC pulldowns | 5.1k 1% | UNI-ROYAL | 0402WGF5101TCE | Resistor_SMD:R_0402_1005Metric | C25905 | SMT basic | POPULATE | One resistor per CC pin
PROVISIONAL | R114,R115 | 2 | USB source damping | 22 ohm 1% | Multiple | TBD | Resistor_SMD:R_0402_1005Metric | TBD | SMT | POPULATE | R114 is USB D+ and R115 is USB D-; place at U1 and tune only if needed
PROVISIONAL | R116 | 1 | USB shield bleed | 1M 1% | Multiple | TBD | Resistor_SMD:R_0402_1005Metric | TBD | SMT | POPULATE | Parallel with C111 between shield and logic ground; validate chassis strategy
EXACT_CANDIDATE | R81,R82 | 2 | Hashboard UART damping | 33 ohm 1% | UNI-ROYAL | 0402WGF330JTCE | Resistor_SMD:R_0402_1005Metric | C25105 | SMT basic | POPULATE | R81 TX and R82 RX; R82 remains a scope-tunable provisional value
EXACT_CANDIDATE | R90 | 1 | Profile-gated hashboard RESET series link | 33 ohm 1% | UNI-ROYAL | 0402WGF330JTCE | Resistor_SMD:R_0402_1005Metric | C25105 | SMT basic | DNP | Default S21-safe assembly leaves link open; populate only for an exact validated legacy-reset profile
EXACT_CANDIDATE | R100,R101,R102 | 3 | Fan SMBus and alert pullups | 4.7k 1% | UNI-ROYAL | 0402WGF4701TCE | Resistor_SMD:R_0402_1005Metric | C25900 | SMT basic | POPULATE | FAN_SDA/FAN_SCL/FAN_ALERT_N pullups to 3V3
PROVISIONAL | R85,R86,R87,R88 | 4 | Split-domain hashboard I2C pullups | 4.7k 1% | UNI-ROYAL | 0402WGF4701TCE | Resistor_SMD:R_0402_1005Metric | C25900 | SMT basic | POPULATE | Two controller-side pulls to 3V3 and two cable-side pulls to switched HB_3V3
EXACT_CANDIDATE | R93,R95,R97 | 3 | Hashboard address default-low straps | 4.7k 1% | UNI-ROYAL | 0402WGF4701TCE | Resistor_SMD:R_0402_1005Metric | C25900 | SMT basic | POPULATE | Default-low side of three mutually exclusive strap pairs
PROVISIONAL | R94,R96,R98 | 3 | Hashboard address high straps | 0 ohm | Multiple | TBD | Resistor_SMD:R_0402_1005Metric | TBD | SMT | DNP | Optional high side connects only to switched HB_3V3; populate instead of corresponding low strap after profile validation
PROVISIONAL | R201,R204,R207,R210 | 4 | Fan tach pullups | 36k 1% | YAGEO | RC0402FR-0736KL | Resistor_SMD:R_0402_1005Metric | C137999 | SMT extended | POPULATE | Starting value; validate rise time and RPM with the exact fans
EXACT_CANDIDATE | R103 | 1 | EMC2305 startup strap | 22k 1% | UNI-ROYAL | 0402WGF2202TCE | Resistor_SMD:R_0402_1005Metric | C25768 | SMT basic | POPULATE | Datasheet decode selects 100% default drive
PROVISIONAL | R104 | 1 | EMC2305 address strap | 33k 1% | UNI-ROYAL | 0402WGF3302TCE | Resistor_SMD:R_0402_1005Metric | C25779 | SMT basic | POPULATE | Confirm decoded SMBus address; firmware probes
PROVISIONAL | RFB1 | 1 | Buck feedback top | 69.8k 1% | Multiple | TBD | Resistor_SMD:R_0402_1005Metric | TBD | SMT | POPULATE | AP64501 DS41980 Table 1 3.3 V starting value; verify tolerance and placement
PROVISIONAL | RFB2 | 1 | Buck feedback bottom | 22.1k 1% | Multiple | TBD | Resistor_SMD:R_0402_1005Metric | TBD | SMT | POPULATE | AP64501 DS41980 Table 1 3.3 V starting value
PROVISIONAL | R65 | 1 | Buck compensation resistor | 10.5k 1% | Multiple | TBD | Resistor_SMD:R_0402_1005Metric | TBD | SMT | POPULATE | AP64501 DS41980 Table 1 starting value; validate loop stability
PROVISIONAL | C15 | 1 | Buck bootstrap capacitor | 100nF 50 V X7R | Samsung Electro-Mechanics | CL05B104KB54PNC | Capacitor_SMD:C_0402_1005Metric | C307331 | SMT extended | POPULATE | Connect directly from AP64501 BST to SW; quote-time stock/substitution check required
PROVISIONAL | C16 | 1 | Buck soft-start capacitor | 10nF X7R | Multiple | TBD | Capacitor_SMD:C_0402_1005Metric | TBD | SMT | POPULATE | DS41980 starting value gives approximately 4 ms soft start
PROVISIONAL | C17 | 1 | Buck compensation capacitor | 2.7nF X7R | Multiple | TBD | Capacitor_SMD:C_0402_1005Metric | TBD | SMT | POPULATE | AP64501 DS41980 Table 1 starting value; validate loop stability
PROVISIONAL | C18 | 1 | Buck optional high-frequency compensation capacitor | 56pF C0G | Multiple | TBD | Capacitor_SMD:C_0402_1005Metric | TBD | SMT | DNP | DS41980 Table 1 C6 option from COMP to GND; fit only after loop/load-transient validation
PROVISIONAL | CIN1,CIN2,CIN3,CIN4 | 4 | Buck input ceramic | 10uF 50 V X7R | Multiple | TBD | Capacitor_SMD:C_1210_3225Metric | TBD | SMT extended | SELECT_BEFORE_RELEASE | Check effective capacitance at 15 V plus transient margin
PROVISIONAL | COUT1,COUT2,COUT3 | 3 | Buck output ceramic | 22uF 10 V X7R | Multiple | TBD | Capacitor_SMD:C_0805_2012Metric | TBD | SMT extended | SELECT_BEFORE_RELEASE | DS41980 Table 1 starting bank; verify DC-bias capacitance and load transients
PROVISIONAL | C50 | 1 | Hashboard load-switch timing capacitor | 1nF X7R | Multiple | TBD | Capacitor_SMD:C_0402_1005Metric | TBD | SMT | POPULATE | TPS22917 CT to VIN/3V3; approximately 3.8 ms turn-on; validate J10 pin-16 inrush
PROVISIONAL | C51,C52 | 2 | Hashboard load-switch local bypass | 1uF | Multiple | TBD | Capacitor_SMD:C_0402_1005Metric | TBD | SMT | POPULATE | C51 at U5 VIN and C52 at switched HB_3V3; select voltage/dielectric and validate inrush
PROVISIONAL | C70 | 1 | Rail-monitor filter capacitor | 10nF | Multiple | TBD | Capacitor_SMD:C_0402_1005Metric | TBD | SMT | POPULATE | With R70/R71; validate ADC settling and noise
EXACT_CANDIDATE | C1,C2,C80,C81,C100,C102,C103,C104 | 8 | IC decoupling | 100nF 50 V X7R | Samsung Electro-Mechanics | CL05B104KB54PNC | Capacitor_SMD:C_0402_1005Metric | C307331 | SMT extended | POPULATE | Frozen schematic count is eight decouplers; place at the associated supply pins; quote-time stock/substitution check required
PROVISIONAL | C110 | 1 | ESP EN delay capacitor | 1uF | Multiple | TBD | Capacitor_SMD:C_0402_1005Metric | TBD | SMT | POPULATE | Works with R110; validate boot and brownout behavior
PROVISIONAL | C101 | 1 | EMC2305 local bulk | 1uF | Multiple | TBD | Capacitor_SMD:C_0805_2012Metric | TBD | SMT | POPULATE | Place at U2 VDD; select voltage/dielectric
PROVISIONAL | C3 | 1 | Optional ESP 3.3 V rail bulk | 220uF low ESR | Multiple | TBD | Capacitor_SMD:CP_Elec_8x10.2 | TBD | Manual or SMT | DNP | Default open: AP64501 Table-1 compensation assumes the ceramic output bank; select exact C3 ESR/capacitance and validate Bode/load-step response before population
PROVISIONAL | C20,C21 | 2 | Fan rail bulk | 470uF 25 V low ESR | Multiple | TBD | Capacitor_THT:CP_Radial_D10.0mm_P5.00mm | TBD | THT/manual | SELECT_BEFORE_RELEASE | Place near fan branches; size from simultaneous startup/stall measurement
PROVISIONAL | C111 | 1 | USB shield coupling capacitor | 1nF 2 kV | Multiple | TBD | Capacitor_SMD:C_0805_2012Metric | TBD | SMT extended | POPULATE | Parallel with R116 between shield and logic ground; select a safety/voltage-appropriate exact part
EXACT_CANDIDATE | C112 | 1 | USB ESD local VBUS bypass | 100nF 50 V X7R | Samsung Electro-Mechanics | CL05B104KB54PNC | Capacitor_SMD:C_0402_1005Metric | C307331 | SMT extended | POPULATE | Place directly between U9 USBLC6 pin 5 VBUS and pin 2 GND with minimal loop area per ST Figure 17
PROVISIONAL | C200,C201,C202,C203 | 4 | Optional fan tach filters | 100pF C0G | Multiple | TBD | Capacitor_SMD:C_0402_1005Metric | TBD | SMT | DNP | Default open; populate only after exact-fan tach waveform validation
EXACT_CANDIDATE | TP1,TP2,TP3,TP4,TP5,TP6,TP7,TP8,TP9,TP10,TP11,TP12,TP13,TP14,TP15,TP16,TP17,TP18,TP19,TP20,TP21,TP22,TP23,TP24,TP25,TP26,TP27,TP28,TP29,TP30,TP31,TP32,TP33,TP34,TP35,TP36,TP37 | 37 | Labeled test points | Bare 1.0 mm SMT pads | N/A | N/A | TestPoint:TestPoint_Pad_D1.0mm | N/A | Bare PCB | PCB_FEATURE | Frozen schematic contains TP1 through TP37; these are copper features, not purchased components
TBD | FEXT1 | 1 | External inline fan-rail fuse | Measured-value fuse | Target-dependent | TBD | Off-board | TBD | Manual | REQUIRED_EXTERNAL | Off-board system item; size from four-fan simultaneous stall/start current and selected connector/cable ratings

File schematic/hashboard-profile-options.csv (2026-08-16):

Profile | ASIC | U5 pin-16 switch | U6 UART/PLUG | U7 I2C | U12 reset buffer | RESET series link | Firmware reset policy | Notes
S19 XP / S19j XP | BM1366 | POPULATE 3V3 | POPULATE A=3V3 B=3V3 | POPULATE TMUX1511 | POPULATE | POPULATE 33R only after exact-SKU validation | Profile-controlled after exact-SKU validation | First-wave target; chip count and baud are per exact SKU
S19k Pro | BM1366 | POPULATE 3V3 | POPULATE A=3V3 B=3V3 | POPULATE TMUX1511 | POPULATE | POPULATE 33R only after exact-SKU validation | Profile-controlled after exact-SKU validation | Confirm cable orientation and local-voltage command on a donor board
S21 | BM1368 | POPULATE 3V3 | POPULATE A=3V3 B=3V3 | POPULATE TMUX1511 | POPULATE BUT KEEP DISABLED | DNP / OPEN | NEVER enable or toggle U12 | NoPIC profile; hardware link is open; GPIO4 remains high and HB_RESET stays high impedance
S21 Pro / S21 XP / S21+ | BM1370 | POPULATE 3V3 | POPULATE A=3V3 B=3V3 | POPULATE TMUX1511 | POPULATE | DNP until exact-SKU validation | Exact-SKU policy required | Do not inherit S21 BM1368 reset behavior without bench confirmation
S19 / S19 Pro | BM1398 | POPULATE 3V3 | POPULATE A=3V3 B=3V3 | POPULATE TMUX1511 | POPULATE | DNP until driver and profile exist | Unsupported until driver and exact profile exist | Hardware connector compatible; current ESP-Miner lacks this ASIC driver
S19j Pro | BM1362 | POPULATE 3V3 | POPULATE A=3V3 B=3V3 | POPULATE TMUX1511 | POPULATE | DNP until driver and profile exist | Unsupported until driver and exact profile exist | Hardware connector compatible; current ESP-Miner lacks this ASIC driver
Unknown 16-used cable target | Unknown | OFF | DISABLED | DISABLED | DISABLED | DNP / OPEN | No reset activity | J10 remains fitted but pin 16 and all active signal drivers stay off until identified

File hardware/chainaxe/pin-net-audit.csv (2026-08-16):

Component | LibID | Pin | PinFunction | ExpectedConnection | ActualConnection | Status
C1 | Device:C | 1 | ~ | 3V3 | 3V3 | PASS
C1 | Device:C | 2 | ~ | GND | GND | PASS
C2 | Device:C | 1 | ~ | 3V3 | 3V3 | PASS
C2 | Device:C | 2 | ~ | GND | GND | PASS
C3 | Device:C_Polarized | 1 | ~ | 3V3 | 3V3 | PASS
C3 | Device:C_Polarized | 2 | ~ | GND | GND | PASS
C15 | Device:C | 1 | ~ | BUCK_BST | BUCK_BST | PASS
C15 | Device:C | 2 | ~ | BUCK_SW | BUCK_SW | PASS
C16 | Device:C | 1 | ~ | BUCK_SS | BUCK_SS | PASS
C16 | Device:C | 2 | ~ | GND | GND | PASS
C17 | Device:C | 1 | ~ | BUCK_COMP_RC | BUCK_COMP_RC | PASS
C17 | Device:C | 2 | ~ | GND | GND | PASS
C18 | Device:C | 1 | ~ | BUCK_COMP | BUCK_COMP | PASS
C18 | Device:C | 2 | ~ | GND | GND | PASS
C20 | Device:C_Polarized | 1 | ~ | FAN_12V | FAN_12V | PASS
C20 | Device:C_Polarized | 2 | ~ | GND | GND | PASS
C21 | Device:C_Polarized | 1 | ~ | FAN_12V | FAN_12V | PASS
C21 | Device:C_Polarized | 2 | ~ | GND | GND | PASS
C50 | Device:C | 1 | ~ | HB_3V3_CT | HB_3V3_CT | PASS
C50 | Device:C | 2 | ~ | 3V3 | 3V3 | PASS
C51 | Device:C | 1 | ~ | 3V3 | 3V3 | PASS
C51 | Device:C | 2 | ~ | GND | GND | PASS
C52 | Device:C | 1 | ~ | HB_3V3 | HB_3V3 | PASS
C52 | Device:C | 2 | ~ | GND | GND | PASS
C70 | Device:C | 1 | ~ | RAIL_MON | RAIL_MON | PASS
C70 | Device:C | 2 | ~ | GND | GND | PASS
C80 | Device:C | 1 | ~ | 3V3 | 3V3 | PASS
C80 | Device:C | 2 | ~ | GND | GND | PASS
C81 | Device:C | 1 | ~ | HB_3V3 | HB_3V3 | PASS
C81 | Device:C | 2 | ~ | GND | GND | PASS
C100 | Device:C | 1 | ~ | 3V3 | 3V3 | PASS
C100 | Device:C | 2 | ~ | GND | GND | PASS
C101 | Device:C | 1 | ~ | 3V3 | 3V3 | PASS
C101 | Device:C | 2 | ~ | GND | GND | PASS
C102 | Device:C | 1 | ~ | 3V3 | 3V3 | PASS
C102 | Device:C | 2 | ~ | GND | GND | PASS
C103 | Device:C | 1 | ~ | HB_3V3 | HB_3V3 | PASS
C103 | Device:C | 2 | ~ | GND | GND | PASS
C104 | Device:C | 1 | ~ | HB_3V3 | HB_3V3 | PASS
C104 | Device:C | 2 | ~ | GND | GND | PASS
C110 | Device:C | 1 | ~ | ESP_EN | ESP_EN | PASS
C110 | Device:C | 2 | ~ | GND | GND | PASS
C111 | Device:C | 1 | ~ | USB_SHIELD | USB_SHIELD | PASS
C111 | Device:C | 2 | ~ | GND | GND | PASS
C112 | Device:C | 1 | ~ | USB_VBUS | USB_VBUS | PASS
C112 | Device:C | 2 | ~ | GND | GND | PASS
C200 | Device:C | 1 | ~ | FAN_TACH1 | FAN_TACH1 | PASS
C200 | Device:C | 2 | ~ | GND | GND | PASS
C201 | Device:C | 1 | ~ | FAN_TACH2 | FAN_TACH2 | PASS
C201 | Device:C | 2 | ~ | GND | GND | PASS
C202 | Device:C | 1 | ~ | FAN_TACH3 | FAN_TACH3 | PASS
C202 | Device:C | 2 | ~ | GND | GND | PASS
C203 | Device:C | 1 | ~ | FAN_TACH4 | FAN_TACH4 | PASS
C203 | Device:C | 2 | ~ | GND | GND | PASS
CIN1 | Device:C | 1 | ~ | LOGIC_IN | LOGIC_IN | PASS
CIN1 | Device:C | 2 | ~ | GND | GND | PASS
CIN2 | Device:C | 1 | ~ | LOGIC_IN | LOGIC_IN | PASS
CIN2 | Device:C | 2 | ~ | GND | GND | PASS
CIN3 | Device:C | 1 | ~ | LOGIC_IN | LOGIC_IN | PASS
CIN3 | Device:C | 2 | ~ | GND | GND | PASS
CIN4 | Device:C | 1 | ~ | LOGIC_IN | LOGIC_IN | PASS
CIN4 | Device:C | 2 | ~ | GND | GND | PASS
COUT1 | Device:C | 1 | ~ | 3V3 | 3V3 | PASS
COUT1 | Device:C | 2 | ~ | GND | GND | PASS
COUT2 | Device:C | 1 | ~ | 3V3 | 3V3 | PASS
COUT2 | Device:C | 2 | ~ | GND | GND | PASS
COUT3 | Device:C | 1 | ~ | 3V3 | 3V3 | PASS
COUT3 | Device:C | 2 | ~ | GND | GND | PASS
D1 | Device:D_Schottky | 1 | K | LOGIC_IN | LOGIC_IN | PASS
D1 | Device:D_Schottky | 2 | A | VIN_LOGIC_12_15 | VIN_LOGIC_12_15 | PASS
D2 | Device:D_Schottky | 1 | K | LOGIC_IN | LOGIC_IN | PASS
D2 | Device:D_Schottky | 2 | A | FAN_TO_LOGIC_FEED | FAN_TO_LOGIC_FEED | PASS
D3 | Device:D_Schottky | 1 | K | LOGIC_IN | LOGIC_IN | PASS
D3 | Device:D_Schottky | 2 | A | USB_VBUS | USB_VBUS | PASS
D4 | Device:D_Zener | 1 | K | FAN_12V | FAN_12V | PASS
D4 | Device:D_Zener | 2 | A | GND | GND | PASS
D5 | Device:D_TVS | 1 | A1 | VIN_LOGIC_12_15 | VIN_LOGIC_12_15 | PASS
D5 | Device:D_TVS | 2 | A2 | GND | GND | PASS
J1 | Connector_Generic:Conn_02x03_Odd_Even | 1 | Pin_1 | GND | GND | PASS
J1 | Connector_Generic:Conn_02x03_Odd_Even | 2 | Pin_2 | GND | GND | PASS
J1 | Connector_Generic:Conn_02x03_Odd_Even | 3 | Pin_3 | GND | GND | PASS
J1 | Connector_Generic:Conn_02x03_Odd_Even | 4 | Pin_4 | FAN_12V_RAW | FAN_12V_RAW | PASS
J1 | Connector_Generic:Conn_02x03_Odd_Even | 5 | Pin_5 | FAN_12V_RAW | FAN_12V_RAW | PASS
J1 | Connector_Generic:Conn_02x03_Odd_Even | 6 | Pin_6 | FAN_12V_RAW | FAN_12V_RAW | PASS
J2 | Connector_Generic:Conn_02x02_Odd_Even | 1 | Pin_1 | GND | GND | PASS
J2 | Connector_Generic:Conn_02x02_Odd_Even | 2 | Pin_2 | FAN_12V | FAN_12V | PASS
J2 | Connector_Generic:Conn_02x02_Odd_Even | 3 | Pin_3 | FAN_TACH1 | FAN_TACH1 | PASS
J2 | Connector_Generic:Conn_02x02_Odd_Even | 4 | Pin_4 | FAN_PWM1 | FAN_PWM1 | PASS
J3 | Connector_Generic:Conn_02x02_Odd_Even | 1 | Pin_1 | GND | GND | PASS
J3 | Connector_Generic:Conn_02x02_Odd_Even | 2 | Pin_2 | FAN_12V | FAN_12V | PASS
J3 | Connector_Generic:Conn_02x02_Odd_Even | 3 | Pin_3 | FAN_TACH2 | FAN_TACH2 | PASS
J3 | Connector_Generic:Conn_02x02_Odd_Even | 4 | Pin_4 | FAN_PWM2 | FAN_PWM2 | PASS
J4 | Connector_Generic:Conn_02x02_Odd_Even | 1 | Pin_1 | GND | GND | PASS
J4 | Connector_Generic:Conn_02x02_Odd_Even | 2 | Pin_2 | FAN_12V | FAN_12V | PASS
J4 | Connector_Generic:Conn_02x02_Odd_Even | 3 | Pin_3 | FAN_TACH3 | FAN_TACH3 | PASS
J4 | Connector_Generic:Conn_02x02_Odd_Even | 4 | Pin_4 | FAN_PWM3 | FAN_PWM3 | PASS
J5 | Connector_Generic:Conn_02x02_Odd_Even | 1 | Pin_1 | GND | GND | PASS
J5 | Connector_Generic:Conn_02x02_Odd_Even | 2 | Pin_2 | FAN_12V | FAN_12V | PASS
J5 | Connector_Generic:Conn_02x02_Odd_Even | 3 | Pin_3 | FAN_TACH4 | FAN_TACH4 | PASS
J5 | Connector_Generic:Conn_02x02_Odd_Even | 4 | Pin_4 | FAN_PWM4 | FAN_PWM4 | PASS
J6 | Connector_Generic:Conn_01x02 | 1 | Pin_1 | VIN_LOGIC_12_15 | VIN_LOGIC_12_15 | PASS
J6 | Connector_Generic:Conn_01x02 | 2 | Pin_2 | GND | GND | PASS
J10 | Connector_Generic:Conn_02x09_Odd_Even | 1 | Pin_1 | GND | GND | PASS
J10 | Connector_Generic:Conn_02x09_Odd_Even | 2 | Pin_2 | GND | GND | PASS
J10 | Connector_Generic:Conn_02x09_Odd_Even | 3 | Pin_3 | HB_SDA | HB_SDA | PASS
J10 | Connector_Generic:Conn_02x09_Odd_Even | 4 | Pin_4 | HB_SCL | HB_SCL | PASS
J10 | Connector_Generic:Conn_02x09_Odd_Even | 5 | Pin_5 | HB_PLUG | HB_PLUG | PASS
J10 | Connector_Generic:Conn_02x09_Odd_Even | 6 | Pin_6 | HB_A2 | HB_A2 | PASS
J10 | Connector_Generic:Conn_02x09_Odd_Even | 7 | Pin_7 | HB_A1 | HB_A1 | PASS
J10 | Connector_Generic:Conn_02x09_Odd_Even | 8 | Pin_8 | HB_A0 | HB_A0 | PASS
J10 | Connector_Generic:Conn_02x09_Odd_Even | 9 | Pin_9 | GND | GND | PASS
J10 | Connector_Generic:Conn_02x09_Odd_Even | 10 | Pin_10 | GND | GND | PASS
J10 | Connector_Generic:Conn_02x09_Odd_Even | 11 | Pin_11 | HB_TX | HB_TX | PASS
J10 | Connector_Generic:Conn_02x09_Odd_Even | 12 | Pin_12 | HB_RX | HB_RX | PASS
J10 | Connector_Generic:Conn_02x09_Odd_Even | 13 | Pin_13 | GND | GND | PASS
J10 | Connector_Generic:Conn_02x09_Odd_Even | 14 | Pin_14 | GND | GND | PASS
J10 | Connector_Generic:Conn_02x09_Odd_Even | 15 | Pin_15 | HB_RESET | HB_RESET | PASS
J10 | Connector_Generic:Conn_02x09_Odd_Even | 16 | Pin_16 | HB_3V3 | HB_3V3 | PASS
J10 | Connector_Generic:Conn_02x09_Odd_Even | 17 | Pin_17 | NC | NC | PASS
J10 | Connector_Generic:Conn_02x09_Odd_Even | 18 | Pin_18 | NC | NC | PASS
J30 | ChainAxe:USB_C_Receptacle_USB2.0 | A1 | GND | GND | GND | PASS
J30 | ChainAxe:USB_C_Receptacle_USB2.0 | A12 | GND | GND | GND | PASS
J30 | ChainAxe:USB_C_Receptacle_USB2.0 | A4 | VBUS | USB_VBUS | USB_VBUS | PASS
J30 | ChainAxe:USB_C_Receptacle_USB2.0 | A5 | CC1 | USB_CC1 | USB_CC1 | PASS
J30 | ChainAxe:USB_C_Receptacle_USB2.0 | A6 | D+ | USB_DP_CONN | USB_DP_CONN | PASS
J30 | ChainAxe:USB_C_Receptacle_USB2.0 | A7 | D- | USB_DN_CONN | USB_DN_CONN | PASS
J30 | ChainAxe:USB_C_Receptacle_USB2.0 | A8 | SBU1 | NC | NC | PASS
J30 | ChainAxe:USB_C_Receptacle_USB2.0 | A9 | VBUS | USB_VBUS | USB_VBUS | PASS
J30 | ChainAxe:USB_C_Receptacle_USB2.0 | B1 | GND | GND | GND | PASS
J30 | ChainAxe:USB_C_Receptacle_USB2.0 | B12 | GND | GND | GND | PASS
J30 | ChainAxe:USB_C_Receptacle_USB2.0 | B4 | VBUS | USB_VBUS | USB_VBUS | PASS
J30 | ChainAxe:USB_C_Receptacle_USB2.0 | B5 | CC2 | USB_CC2 | USB_CC2 | PASS
J30 | ChainAxe:USB_C_Receptacle_USB2.0 | B6 | D+ | USB_DP_CONN | USB_DP_CONN | PASS
J30 | ChainAxe:USB_C_Receptacle_USB2.0 | B7 | D- | USB_DN_CONN | USB_DN_CONN | PASS
J30 | ChainAxe:USB_C_Receptacle_USB2.0 | B8 | SBU2 | NC | NC | PASS
J30 | ChainAxe:USB_C_Receptacle_USB2.0 | B9 | VBUS | USB_VBUS | USB_VBUS | PASS
J30 | ChainAxe:USB_C_Receptacle_USB2.0 | S1 | SHIELD | USB_SHIELD | USB_SHIELD | PASS
JP1 | Jumper:SolderJumper_2_Open | 1 | A | FAN_12V | FAN_12V | PASS
JP1 | Jumper:SolderJumper_2_Open | 2 | B | FAN_TO_LOGIC_FEED | FAN_TO_LOGIC_FEED | PASS
L1 | ChainAxe:SRP5030T-3R3M | 1 | 1 | BUCK_SW | BUCK_SW | PASS
L1 | ChainAxe:SRP5030T-3R3M | 2 | 2 | 3V3 | 3V3 | PASS
Q1 | Transistor_FET:Q_NMOS_GSD | 1 | G | FAN_GATE1 | FAN_GATE1 | PASS
Q1 | Transistor_FET:Q_NMOS_GSD | 2 | S | GND | GND | PASS
Q1 | Transistor_FET:Q_NMOS_GSD | 3 | D | FAN_PWM1 | FAN_PWM1 | PASS
Q2 | Transistor_FET:Q_NMOS_GSD | 1 | G | FAN_GATE2 | FAN_GATE2 | PASS
Q2 | Transistor_FET:Q_NMOS_GSD | 2 | S | GND | GND | PASS
Q2 | Transistor_FET:Q_NMOS_GSD | 3 | D | FAN_PWM2 | FAN_PWM2 | PASS
Q3 | Transistor_FET:Q_NMOS_GSD | 1 | G | FAN_GATE3 | FAN_GATE3 | PASS
Q3 | Transistor_FET:Q_NMOS_GSD | 2 | S | GND | GND | PASS
Q3 | Transistor_FET:Q_NMOS_GSD | 3 | D | FAN_PWM3 | FAN_PWM3 | PASS
Q4 | Transistor_FET:Q_NMOS_GSD | 1 | G | FAN_GATE4 | FAN_GATE4 | PASS
Q4 | Transistor_FET:Q_NMOS_GSD | 2 | S | GND | GND | PASS
Q4 | Transistor_FET:Q_NMOS_GSD | 3 | D | FAN_PWM4 | FAN_PWM4 | PASS
Q5 | ChainAxe:DMP3013SFV | 1 | SOURCE | FAN_12V | FAN_12V | PASS
Q5 | ChainAxe:DMP3013SFV | 2 | SOURCE | FAN_12V | FAN_12V | PASS
Q5 | ChainAxe:DMP3013SFV | 3 | SOURCE | FAN_12V | FAN_12V | PASS
Q5 | ChainAxe:DMP3013SFV | 4 | GATE | FAN_RPP_GATE | FAN_RPP_GATE | PASS
Q5 | ChainAxe:DMP3013SFV | 5 | DRAIN | FAN_12V_RAW | FAN_12V_RAW | PASS
Q5 | ChainAxe:DMP3013SFV | 6 | DRAIN | FAN_12V_RAW | FAN_12V_RAW | PASS
Q5 | ChainAxe:DMP3013SFV | 7 | DRAIN | FAN_12V_RAW | FAN_12V_RAW | PASS
Q5 | ChainAxe:DMP3013SFV | 8 | DRAIN | FAN_12V_RAW | FAN_12V_RAW | PASS
Q6 | ChainAxe:DMP3013SFV | 1 | SOURCE | FAN_12V | FAN_12V | PASS
Q6 | ChainAxe:DMP3013SFV | 2 | SOURCE | FAN_12V | FAN_12V | PASS
Q6 | ChainAxe:DMP3013SFV | 3 | SOURCE | FAN_12V | FAN_12V | PASS
Q6 | ChainAxe:DMP3013SFV | 4 | GATE | FAN_RPP_GATE | FAN_RPP_GATE | PASS
Q6 | ChainAxe:DMP3013SFV | 5 | DRAIN | FAN_12V_RAW | FAN_12V_RAW | PASS
Q6 | ChainAxe:DMP3013SFV | 6 | DRAIN | FAN_12V_RAW | FAN_12V_RAW | PASS
Q6 | ChainAxe:DMP3013SFV | 7 | DRAIN | FAN_12V_RAW | FAN_12V_RAW | PASS
Q6 | ChainAxe:DMP3013SFV | 8 | DRAIN | FAN_12V_RAW | FAN_12V_RAW | PASS
R50 | Device:R | 1 | ~ | HB_IO_PWR_EN | HB_IO_PWR_EN | PASS
R50 | Device:R | 2 | ~ | GND | GND | PASS
R51 | Device:R | 1 | ~ | HB_3V3 | HB_3V3 | PASS
R51 | Device:R | 2 | ~ | HB_QOD | HB_QOD | PASS
R60 | Device:R | 1 | ~ | FAN_RPP_GATE | FAN_RPP_GATE | PASS
R60 | Device:R | 2 | ~ | GND | GND | PASS
R65 | Device:R | 1 | ~ | BUCK_COMP | BUCK_COMP | PASS
R65 | Device:R | 2 | ~ | BUCK_COMP_RC | BUCK_COMP_RC | PASS
R70 | Device:R | 1 | ~ | FAN_12V | FAN_12V | PASS
R70 | Device:R | 2 | ~ | RAIL_MON | RAIL_MON | PASS
R71 | Device:R | 1 | ~ | RAIL_MON | RAIL_MON | PASS
R71 | Device:R | 2 | ~ | GND | GND | PASS
R80 | Device:R | 1 | ~ | HB_XLAT_OE_N | HB_XLAT_OE_N | PASS
R80 | Device:R | 2 | ~ | 3V3 | 3V3 | PASS
R81 | Device:R | 1 | ~ | HB_TX_BUF | HB_TX_BUF | PASS
R81 | Device:R | 2 | ~ | HB_TX | HB_TX | PASS
R82 | Device:R | 1 | ~ | HB_RX | HB_RX | PASS
R82 | Device:R | 2 | ~ | HB_RX_BUF | HB_RX_BUF | PASS
R83 | Device:R | 1 | ~ | HB_PLUG_3V3 | HB_PLUG_3V3 | PASS
R83 | Device:R | 2 | ~ | GND | GND | PASS
R84 | Device:R | 1 | ~ | HB_I2C_EN | HB_I2C_EN | PASS
R84 | Device:R | 2 | ~ | GND | GND | PASS
R85 | Device:R | 1 | ~ | HB_SCL_3V3 | HB_SCL_3V3 | PASS
R85 | Device:R | 2 | ~ | 3V3 | 3V3 | PASS
R86 | Device:R | 1 | ~ | HB_SDA_3V3 | HB_SDA_3V3 | PASS
R86 | Device:R | 2 | ~ | 3V3 | 3V3 | PASS
R87 | Device:R | 1 | ~ | HB_SCL | HB_SCL | PASS
R87 | Device:R | 2 | ~ | HB_3V3 | HB_3V3 | PASS
R88 | Device:R | 1 | ~ | HB_SDA | HB_SDA | PASS
R88 | Device:R | 2 | ~ | HB_3V3 | HB_3V3 | PASS
R89 | Device:R | 1 | ~ | HB_RESET_OE_N | HB_RESET_OE_N | PASS
R89 | Device:R | 2 | ~ | 3V3 | 3V3 | PASS
R90 | Device:R | 1 | ~ | HB_RESET_DRV | HB_RESET_DRV | PASS
R90 | Device:R | 2 | ~ | HB_RESET | HB_RESET | PASS
R91 | Device:R | 1 | ~ | HB_RESET | HB_RESET | PASS
R91 | Device:R | 2 | ~ | HB_3V3 | HB_3V3 | PASS
R92 | Device:R | 1 | ~ | HB_RESET | HB_RESET | PASS
R92 | Device:R | 2 | ~ | GND | GND | PASS
R93 | Device:R | 1 | ~ | HB_A0 | HB_A0 | PASS
R93 | Device:R | 2 | ~ | GND | GND | PASS
R94 | Device:R | 1 | ~ | HB_A0 | HB_A0 | PASS
R94 | Device:R | 2 | ~ | HB_3V3 | HB_3V3 | PASS
R95 | Device:R | 1 | ~ | HB_A1 | HB_A1 | PASS
R95 | Device:R | 2 | ~ | GND | GND | PASS
R96 | Device:R | 1 | ~ | HB_A1 | HB_A1 | PASS
R96 | Device:R | 2 | ~ | HB_3V3 | HB_3V3 | PASS
R97 | Device:R | 1 | ~ | HB_A2 | HB_A2 | PASS
R97 | Device:R | 2 | ~ | GND | GND | PASS
R98 | Device:R | 1 | ~ | HB_A2 | HB_A2 | PASS
R98 | Device:R | 2 | ~ | HB_3V3 | HB_3V3 | PASS
R100 | Device:R | 1 | ~ | FAN_SDA | FAN_SDA | PASS
R100 | Device:R | 2 | ~ | 3V3 | 3V3 | PASS
R101 | Device:R | 1 | ~ | FAN_SCL | FAN_SCL | PASS
R101 | Device:R | 2 | ~ | 3V3 | 3V3 | PASS
R102 | Device:R | 1 | ~ | FAN_ALERT_N | FAN_ALERT_N | PASS
R102 | Device:R | 2 | ~ | 3V3 | 3V3 | PASS
R103 | Device:R | 1 | ~ | EMC_CLK | EMC_CLK | PASS
R103 | Device:R | 2 | ~ | 3V3 | 3V3 | PASS
R104 | Device:R | 1 | ~ | EMC_ADDR | EMC_ADDR | PASS
R104 | Device:R | 2 | ~ | 3V3 | 3V3 | PASS
R105 | Device:R | 1 | ~ | FAN_ARM | FAN_ARM | PASS
R105 | Device:R | 2 | ~ | GND | GND | PASS
R106 | Device:R | 1 | ~ | EMC_PWM1 | EMC_PWM1 | PASS
R106 | Device:R | 2 | ~ | GND | GND | PASS
R107 | Device:R | 1 | ~ | EMC_PWM2 | EMC_PWM2 | PASS
R107 | Device:R | 2 | ~ | GND | GND | PASS
R108 | Device:R | 1 | ~ | EMC_PWM3 | EMC_PWM3 | PASS
R108 | Device:R | 2 | ~ | GND | GND | PASS
R109 | Device:R | 1 | ~ | EMC_PWM4 | EMC_PWM4 | PASS
R109 | Device:R | 2 | ~ | GND | GND | PASS
R110 | Device:R | 1 | ~ | 3V3 | 3V3 | PASS
R110 | Device:R | 2 | ~ | ESP_EN | ESP_EN | PASS
R111 | Device:R | 1 | ~ | 3V3 | 3V3 | PASS
R111 | Device:R | 2 | ~ | BOOT_N | BOOT_N | PASS
R112 | Device:R | 1 | ~ | USB_CC1 | USB_CC1 | PASS
R112 | Device:R | 2 | ~ | GND | GND | PASS
R113 | Device:R | 1 | ~ | USB_CC2 | USB_CC2 | PASS
R113 | Device:R | 2 | ~ | GND | GND | PASS
R114 | Device:R | 1 | ~ | USB_DP_PROT | USB_DP_PROT | PASS
R114 | Device:R | 2 | ~ | USB_DP | USB_DP | PASS
R115 | Device:R | 1 | ~ | USB_DN_PROT | USB_DN_PROT | PASS
R115 | Device:R | 2 | ~ | USB_DN | USB_DN | PASS
R116 | Device:R | 1 | ~ | USB_SHIELD | USB_SHIELD | PASS
R116 | Device:R | 2 | ~ | GND | GND | PASS
R200 | Device:R | 1 | ~ | FAN_GATE1 | FAN_GATE1 | PASS
R200 | Device:R | 2 | ~ | GND | GND | PASS
R201 | Device:R | 1 | ~ | FAN_TACH1 | FAN_TACH1 | PASS
R201 | Device:R | 2 | ~ | 3V3 | 3V3 | PASS
R203 | Device:R | 1 | ~ | FAN_GATE2 | FAN_GATE2 | PASS
R203 | Device:R | 2 | ~ | GND | GND | PASS
R204 | Device:R | 1 | ~ | FAN_TACH2 | FAN_TACH2 | PASS
R204 | Device:R | 2 | ~ | 3V3 | 3V3 | PASS
R206 | Device:R | 1 | ~ | FAN_GATE3 | FAN_GATE3 | PASS
R206 | Device:R | 2 | ~ | GND | GND | PASS
R207 | Device:R | 1 | ~ | FAN_TACH3 | FAN_TACH3 | PASS
R207 | Device:R | 2 | ~ | 3V3 | 3V3 | PASS
R209 | Device:R | 1 | ~ | FAN_GATE4 | FAN_GATE4 | PASS
R209 | Device:R | 2 | ~ | GND | GND | PASS
R210 | Device:R | 1 | ~ | FAN_TACH4 | FAN_TACH4 | PASS
R210 | Device:R | 2 | ~ | 3V3 | 3V3 | PASS
RFB1 | Device:R | 1 | ~ | 3V3 | 3V3 | PASS
RFB1 | Device:R | 2 | ~ | BUCK_FB | BUCK_FB | PASS
RFB2 | Device:R | 1 | ~ | BUCK_FB | BUCK_FB | PASS
RFB2 | Device:R | 2 | ~ | GND | GND | PASS
SW1 | Switch:SW_Push | 1 | 1 | BOOT_N | BOOT_N | PASS
SW1 | Switch:SW_Push | 2 | 2 | GND | GND | PASS
SW2 | Switch:SW_Push | 1 | 1 | ESP_EN | ESP_EN | PASS
SW2 | Switch:SW_Push | 2 | 2 | GND | GND | PASS
TP1 | Connector:TestPoint | 1 | 1 | FAN_12V_RAW | FAN_12V_RAW | PASS
TP2 | Connector:TestPoint | 1 | 1 | FAN_12V | FAN_12V | PASS
TP3 | Connector:TestPoint | 1 | 1 | VIN_LOGIC_12_15 | VIN_LOGIC_12_15 | PASS
TP4 | Connector:TestPoint | 1 | 1 | LOGIC_IN | LOGIC_IN | PASS
TP5 | Connector:TestPoint | 1 | 1 | 3V3 | 3V3 | PASS
TP6 | Connector:TestPoint | 1 | 1 | HB_3V3 | HB_3V3 | PASS
TP7 | Connector:TestPoint | 1 | 1 | RAIL_MON | RAIL_MON | PASS
TP8 | Connector:TestPoint | 1 | 1 | DBG_TX | DBG_TX | PASS
TP9 | Connector:TestPoint | 1 | 1 | DBG_RX | DBG_RX | PASS
TP10 | Connector:TestPoint | 1 | 1 | EXP_GPIO5 | EXP_GPIO5 | PASS
TP11 | Connector:TestPoint | 1 | 1 | EXP_GPIO6 | EXP_GPIO6 | PASS
TP12 | Connector:TestPoint | 1 | 1 | GND | GND | PASS
TP13 | Connector:TestPoint | 1 | 1 | 3V3 | 3V3 | PASS
TP14 | Connector:TestPoint | 1 | 1 | FAN_PWM1 | FAN_PWM1 | PASS
TP15 | Connector:TestPoint | 1 | 1 | FAN_TACH1 | FAN_TACH1 | PASS
TP16 | Connector:TestPoint | 1 | 1 | FAN_PWM2 | FAN_PWM2 | PASS
TP17 | Connector:TestPoint | 1 | 1 | FAN_TACH2 | FAN_TACH2 | PASS
TP18 | Connector:TestPoint | 1 | 1 | FAN_PWM3 | FAN_PWM3 | PASS
TP19 | Connector:TestPoint | 1 | 1 | FAN_TACH3 | FAN_TACH3 | PASS
TP20 | Connector:TestPoint | 1 | 1 | FAN_PWM4 | FAN_PWM4 | PASS
TP21 | Connector:TestPoint | 1 | 1 | FAN_TACH4 | FAN_TACH4 | PASS
TP22 | Connector:TestPoint | 1 | 1 | FAN_ARM | FAN_ARM | PASS
TP23 | Connector:TestPoint | 1 | 1 | FAN_ALERT_N | FAN_ALERT_N | PASS
TP24 | Connector:TestPoint | 1 | 1 | FAN_SDA | FAN_SDA | PASS
TP25 | Connector:TestPoint | 1 | 1 | FAN_SCL | FAN_SCL | PASS
TP26 | Connector:TestPoint | 1 | 1 | USB_VBUS | USB_VBUS | PASS
TP27 | Connector:TestPoint | 1 | 1 | HB_RESET_CMD | HB_RESET_CMD | PASS
TP28 | Connector:TestPoint | 1 | 1 | HB_IO_PWR_EN | HB_IO_PWR_EN | PASS
TP29 | Connector:TestPoint | 1 | 1 | HB_TX | HB_TX | PASS
TP30 | Connector:TestPoint | 1 | 1 | HB_RX | HB_RX | PASS
TP31 | Connector:TestPoint | 1 | 1 | HB_PLUG | HB_PLUG | PASS
TP32 | Connector:TestPoint | 1 | 1 | HB_SDA | HB_SDA | PASS
TP33 | Connector:TestPoint | 1 | 1 | HB_SCL | HB_SCL | PASS
TP34 | Connector:TestPoint | 1 | 1 | HB_RESET | HB_RESET | PASS
TP35 | Connector:TestPoint | 1 | 1 | HB_XLAT_OE_N | HB_XLAT_OE_N | PASS
TP36 | Connector:TestPoint | 1 | 1 | HB_I2C_EN | HB_I2C_EN | PASS
TP37 | Connector:TestPoint | 1 | 1 | HB_RESET_OE_N | HB_RESET_OE_N | PASS
U1 | ChainAxe:ESP32-S3-WROOM-1 | 1 | GND | GND | GND | PASS
U1 | ChainAxe:ESP32-S3-WROOM-1 | 2 | 3V3 | 3V3 | 3V3 | PASS
U1 | ChainAxe:ESP32-S3-WROOM-1 | 3 | EN | ESP_EN | ESP_EN | PASS
U1 | ChainAxe:ESP32-S3-WROOM-1 | 4 | GPIO4/TOUCH4/ADC1_CH3 | HB_RESET_OE_N | HB_RESET_OE_N | PASS
U1 | ChainAxe:ESP32-S3-WROOM-1 | 5 | GPIO5/TOUCH5/ADC1_CH4 | EXP_GPIO5 | EXP_GPIO5 | PASS
U1 | ChainAxe:ESP32-S3-WROOM-1 | 6 | GPIO6/TOUCH6/ADC1_CH5 | EXP_GPIO6 | EXP_GPIO6 | PASS
U1 | ChainAxe:ESP32-S3-WROOM-1 | 7 | GPIO7/TOUCH7/ADC1_CH6 | HB_XLAT_OE_N | HB_XLAT_OE_N | PASS
U1 | ChainAxe:ESP32-S3-WROOM-1 | 8 | GPIO15/U0RTS/ADC2_CH4/XTAL_32K_P | NC | NC | PASS
U1 | ChainAxe:ESP32-S3-WROOM-1 | 9 | GPIO16/U0CTS/ADC2_CH5/XTAL_32K_NH5 | NC | NC | PASS
U1 | ChainAxe:ESP32-S3-WROOM-1 | 10 | GPIO17/U1TXD/ADC2_CH6 | HB_TX_3V3 | HB_TX_3V3 | PASS
U1 | ChainAxe:ESP32-S3-WROOM-1 | 11 | GPIO18/U1RXD/ADC2_CH7/CLK_OUT3 | HB_RX_3V3 | HB_RX_3V3 | PASS
U1 | ChainAxe:ESP32-S3-WROOM-1 | 12 | GPIO8/TOUCH8/ADC1_CH7/SUBSPICS1 | FAN_ARM | FAN_ARM | PASS
U1 | ChainAxe:ESP32-S3-WROOM-1 | 13 | GPIO19/U1RTS/ADC2_CH8/CLK_OUT2/USB_D- | USB_DN | USB_DN | PASS
U1 | ChainAxe:ESP32-S3-WROOM-1 | 14 | GPIO20/U1CTS/ADC2_CH9/CLK_OUT1/USB_D+ | USB_DP | USB_DP | PASS
U1 | ChainAxe:ESP32-S3-WROOM-1 | 15 | GPIO3/TOUCH3/ADC1_CH2* | NC | NC | PASS
U1 | ChainAxe:ESP32-S3-WROOM-1 | 16 | *GPIO46 | NC | NC | PASS
U1 | ChainAxe:ESP32-S3-WROOM-1 | 17 | GPIO9/TOUCH9/ADC1_CH8/FSPIHD/SUBSPIHD | HB_I2C_EN | HB_I2C_EN | PASS
U1 | ChainAxe:ESP32-S3-WROOM-1 | 18 | GPIO10/TOUCH10/ADC1_CH9/FSPICS0/FSPIIO4/SUBSPICS0 | HB_IO_PWR_EN | HB_IO_PWR_EN | PASS
U1 | ChainAxe:ESP32-S3-WROOM-1 | 19 | GPIO11/TOUCH11/ADC2_CH0/FSPID/FSPIIO5/SUBSPID | RAIL_MON | RAIL_MON | PASS
U1 | ChainAxe:ESP32-S3-WROOM-1 | 20 | GPIO12/TOUCH12/ADC2_CH1/FSPICLK/FSPIIO6/SUBSPICLK | HB_PLUG_3V3 | HB_PLUG_3V3 | PASS
U1 | ChainAxe:ESP32-S3-WROOM-1 | 21 | GPIO13/TOUCH13/ADC2_CH2/FSPIQ/FSPIIO7/SUBSPIQ | FAN_ALERT_N | FAN_ALERT_N | PASS
U1 | ChainAxe:ESP32-S3-WROOM-1 | 22 | GPIO14/TOUCH14/ADC2_CH3/FSPIWP/FSPIDQS/SUBSPIWP | HB_SDA_3V3 | HB_SDA_3V3 | PASS
U1 | ChainAxe:ESP32-S3-WROOM-1 | 23 | GPIO21 | HB_SCL_3V3 | HB_SCL_3V3 | PASS
U1 | ChainAxe:ESP32-S3-WROOM-1 | 24 | GPIO47/SPICLK_P/SUBSPICLK_P_DIFF | FAN_SDA | FAN_SDA | PASS
U1 | ChainAxe:ESP32-S3-WROOM-1 | 25 | GPIO48/SPICLK_N/SUBSPICLK_N_DIFF | FAN_SCL | FAN_SCL | PASS
U1 | ChainAxe:ESP32-S3-WROOM-1 | 26 | *GPIO45 | NC | NC | PASS
U1 | ChainAxe:ESP32-S3-WROOM-1 | 27 | GPIO0/BOOT* | BOOT_N | BOOT_N | PASS
U1 | ChainAxe:ESP32-S3-WROOM-1 | 28 | SPIIO6/GPIO35/FSPID/SUBSPID | NC | NC | PASS
U1 | ChainAxe:ESP32-S3-WROOM-1 | 29 | SPIIO7/GPIO36/FSPICLK/SUBSPICLK | NC | NC | PASS
U1 | ChainAxe:ESP32-S3-WROOM-1 | 30 | SPIDQS/GPIO37/FSPIQ/SUBSPIQ | NC | NC | PASS
U1 | ChainAxe:ESP32-S3-WROOM-1 | 31 | GPIO38/FSPIWP/SUBSPIWP | NC | NC | PASS
U1 | ChainAxe:ESP32-S3-WROOM-1 | 32 | MTCK/GPIO39/CLK_OUT3/SUBSPICS1 | NC | NC | PASS
U1 | ChainAxe:ESP32-S3-WROOM-1 | 33 | MTDO/GPIO40/CLK_OUT2 | NC | NC | PASS
U1 | ChainAxe:ESP32-S3-WROOM-1 | 34 | MTDI/GPIO41/CLK_OUT1 | NC | NC | PASS
U1 | ChainAxe:ESP32-S3-WROOM-1 | 35 | MTMS/GPIO42 | NC | NC | PASS
U1 | ChainAxe:ESP32-S3-WROOM-1 | 36 | U0RXD/GPIO44/CLK_OUT2 | DBG_RX | DBG_RX | PASS
U1 | ChainAxe:ESP32-S3-WROOM-1 | 37 | U0TXD/GPIO43/CLK_OUT1 | DBG_TX | DBG_TX | PASS
U1 | ChainAxe:ESP32-S3-WROOM-1 | 38 | GPIO2/TOUCH2/ADC1_CH1 | NC | NC | PASS
U1 | ChainAxe:ESP32-S3-WROOM-1 | 39 | GPIO1/TOUCH1/ADC1_CH0 | HB_RESET_CMD | HB_RESET_CMD | PASS
U1 | ChainAxe:ESP32-S3-WROOM-1 | 40 | GND | GND | GND | PASS
U1 | ChainAxe:ESP32-S3-WROOM-1 | 41 | GND | GND | GND | PASS
U2 | ChainAxe:EMC2305-1-AP-TR | 1 | SMDATA | FAN_SDA | FAN_SDA | PASS
U2 | ChainAxe:EMC2305-1-AP-TR | 2 | SMCLK | FAN_SCL | FAN_SCL | PASS
U2 | ChainAxe:EMC2305-1-AP-TR | 3 | VDD | 3V3 | 3V3 | PASS
U2 | ChainAxe:EMC2305-1-AP-TR | 4 | ADDR_SEL | EMC_ADDR | EMC_ADDR | PASS
U2 | ChainAxe:EMC2305-1-AP-TR | 5 | PWM1 | EMC_PWM1 | EMC_PWM1 | PASS
U2 | ChainAxe:EMC2305-1-AP-TR | 6 | TACH1 | FAN_TACH1 | FAN_TACH1 | PASS
U2 | ChainAxe:EMC2305-1-AP-TR | 7 | PWM2 | EMC_PWM2 | EMC_PWM2 | PASS
U2 | ChainAxe:EMC2305-1-AP-TR | 8 | TACH2 | FAN_TACH2 | FAN_TACH2 | PASS
U2 | ChainAxe:EMC2305-1-AP-TR | 9 | PWM3 | EMC_PWM3 | EMC_PWM3 | PASS
U2 | ChainAxe:EMC2305-1-AP-TR | 10 | TACH3 | FAN_TACH3 | FAN_TACH3 | PASS
U2 | ChainAxe:EMC2305-1-AP-TR | 11 | CLK | EMC_CLK | EMC_CLK | PASS
U2 | ChainAxe:EMC2305-1-AP-TR | 12 | ~{ALERT} | FAN_ALERT_N | FAN_ALERT_N | PASS
U2 | ChainAxe:EMC2305-1-AP-TR | 13 | PWM4 | EMC_PWM4 | EMC_PWM4 | PASS
U2 | ChainAxe:EMC2305-1-AP-TR | 14 | TACH4 | FAN_TACH4 | FAN_TACH4 | PASS
U2 | ChainAxe:EMC2305-1-AP-TR | 15 | PWM5 | NC | NC | PASS
U2 | ChainAxe:EMC2305-1-AP-TR | 16 | TACH5 | NC | NC | PASS
U2 | ChainAxe:EMC2305-1-AP-TR | 17 | GND | GND | GND | PASS
U3 | ChainAxe:AP64501SP | 1 | BST | BUCK_BST | BUCK_BST | PASS
U3 | ChainAxe:AP64501SP | 2 | VIN | LOGIC_IN | LOGIC_IN | PASS
U3 | ChainAxe:AP64501SP | 3 | EN | LOGIC_IN | LOGIC_IN | PASS
U3 | ChainAxe:AP64501SP | 4 | SS | BUCK_SS | BUCK_SS | PASS
U3 | ChainAxe:AP64501SP | 5 | FB | BUCK_FB | BUCK_FB | PASS
U3 | ChainAxe:AP64501SP | 6 | COMP | BUCK_COMP | BUCK_COMP | PASS
U3 | ChainAxe:AP64501SP | 7 | GND | GND | GND | PASS
U3 | ChainAxe:AP64501SP | 8 | SW | BUCK_SW | BUCK_SW | PASS
U3 | ChainAxe:AP64501SP | 9 | EP | GND | GND | PASS
U5 | ChainAxe:TPS22917 | 1 | VIN | 3V3 | 3V3 | PASS
U5 | ChainAxe:TPS22917 | 2 | GND | GND | GND | PASS
U5 | ChainAxe:TPS22917 | 3 | ON | HB_IO_PWR_EN | HB_IO_PWR_EN | PASS
U5 | ChainAxe:TPS22917 | 4 | CT | HB_3V3_CT | HB_3V3_CT | PASS
U5 | ChainAxe:TPS22917 | 5 | QOD | HB_QOD | HB_QOD | PASS
U5 | ChainAxe:TPS22917 | 6 | VOUT | HB_3V3 | HB_3V3 | PASS
U6 | ChainAxe:SN74AXC4T774PW | 1 | DIR1 | 3V3 | 3V3 | PASS
U6 | ChainAxe:SN74AXC4T774PW | 2 | DIR2 | GND | GND | PASS
U6 | ChainAxe:SN74AXC4T774PW | 3 | A1 | HB_TX_3V3 | HB_TX_3V3 | PASS
U6 | ChainAxe:SN74AXC4T774PW | 4 | A2 | HB_RX_3V3 | HB_RX_3V3 | PASS
U6 | ChainAxe:SN74AXC4T774PW | 5 | A3 | HB_PLUG_3V3 | HB_PLUG_3V3 | PASS
U6 | ChainAxe:SN74AXC4T774PW | 6 | A4 | GND | GND | PASS
U6 | ChainAxe:SN74AXC4T774PW | 7 | DIR3 | GND | GND | PASS
U6 | ChainAxe:SN74AXC4T774PW | 8 | DIR4 | 3V3 | 3V3 | PASS
U6 | ChainAxe:SN74AXC4T774PW | 9 | OE | HB_XLAT_OE_N | HB_XLAT_OE_N | PASS
U6 | ChainAxe:SN74AXC4T774PW | 10 | GND | GND | GND | PASS
U6 | ChainAxe:SN74AXC4T774PW | 11 | B4 | NC | NC | PASS
U6 | ChainAxe:SN74AXC4T774PW | 12 | B3 | HB_PLUG | HB_PLUG | PASS
U6 | ChainAxe:SN74AXC4T774PW | 13 | B2 | HB_RX_BUF | HB_RX_BUF | PASS
U6 | ChainAxe:SN74AXC4T774PW | 14 | B1 | HB_TX_BUF | HB_TX_BUF | PASS
U6 | ChainAxe:SN74AXC4T774PW | 15 | VCCB | HB_3V3 | HB_3V3 | PASS
U6 | ChainAxe:SN74AXC4T774PW | 16 | VCCA | 3V3 | 3V3 | PASS
U7 | ChainAxe:TMUX1511PWR | 1 | SEL1 | HB_I2C_EN | HB_I2C_EN | PASS
U7 | ChainAxe:TMUX1511PWR | 2 | S1 | HB_SCL_3V3 | HB_SCL_3V3 | PASS
U7 | ChainAxe:TMUX1511PWR | 3 | D1 | HB_SCL | HB_SCL | PASS
U7 | ChainAxe:TMUX1511PWR | 4 | SEL2 | HB_I2C_EN | HB_I2C_EN | PASS
U7 | ChainAxe:TMUX1511PWR | 5 | S2 | HB_SDA_3V3 | HB_SDA_3V3 | PASS
U7 | ChainAxe:TMUX1511PWR | 6 | D2 | HB_SDA | HB_SDA | PASS
U7 | ChainAxe:TMUX1511PWR | 7 | GND | GND | GND | PASS
U7 | ChainAxe:TMUX1511PWR | 8 | D3 | NC | NC | PASS
U7 | ChainAxe:TMUX1511PWR | 9 | S3 | NC | NC | PASS
U7 | ChainAxe:TMUX1511PWR | 10 | SEL3 | GND | GND | PASS
U7 | ChainAxe:TMUX1511PWR | 11 | D4 | NC | NC | PASS
U7 | ChainAxe:TMUX1511PWR | 12 | S4 | NC | NC | PASS
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

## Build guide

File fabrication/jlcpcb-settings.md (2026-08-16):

# JLCPCB-oriented fabrication and assembly settings — Rev A.1

This file records the intended production path; it is not an authorization to order an unreviewed board.

## PCB quote

| Setting | Starting choice | Release note |
|---|---|---|
| Layers | 4 | L2 solid GND; L3 quiet power |
| Size | 100 × 70 mm | Confirm final outline and connector overhang |
| Thickness | 1.6 mm | Match connector/mechanical design |
| Outer copper | 2 oz preferred | Confirm available JLC stack and impedance service |
| Inner copper | 1 oz | Recheck returned stack-up |
| Material | Standard FR-4, Tg ≥135 °C | Consider higher Tg after thermal testing |
| Surface finish | ENIG preferred | QFN/prototype yield; lead-free HASL is an alternate |
| Solder mask | Any high-contrast color | Green usually offers best process latitude |
| Impedance | 90 Ω differential USB | Use JLC's calculator with chosen stack |
| Via | 0.60/0.30 mm starting point | Use smaller only where required |
| Edge routing | Standard | No castellations or controlled-depth features planned |
| Electrical test | Flying probe | Required |

## Assembly quote

- SMT top-side assembly is the default.
- Hand-install or obtain a separate THT quote for J1, J2–J5, J6, J10, and JP1 until part availability, orientation, and mechanical fit are proven.
- Panel fiducials are JLC-managed; retain three local board fiducials away from edge copper and tall connectors.
- Use windowed paste apertures on the EMC2305 and AP64501 exposed pads; target roughly 50–70% paste coverage per package/application guidance and review the generated stencil.
- Keep DNP parts explicit in KiCad variants and exclude them from the uploaded BOM/CPL.
- Keep `RESET_ENABLE_LINK` DNP/open in the default S21-safe assembly. A legacy-reset BOM variant may populate 33 Ω only after the exact profile is validated.
- Do not place a common copper link between J1 `FAN_12V` and J6 `VIN_LOGIC_12_15`; the only permitted option is JP1 followed by D2 into `LOGIC_IN`.

## Required export set

1. Gerber X2 or standard Gerbers for all copper, mask, silk, and Edge.Cuts.
2. Excellon plated/non-plated drill files.
3. Fabrication drawing with stack, thickness, copper, finish, controlled impedance, and tolerances.
4. Assembly drawing showing every connector mating direction, pin 1, J10 positions 17/18 NC, and fan labels `G / 12 / T / P`.
5. BOM with `Comment`, `Designator`, `Footprint`, and exact `LCSC Part #`.
6. CPL/position file from the same final KiCad board, in millimetres, with side and rotation.
7. Read-me identifying every DNP, selection-required, and hand-installed component.

JLC's current KiCad guidance expects BOM and centroid/CPL files generated from the PCB project. Use `bom/jlcpcb-bom-template.csv` only as a column/example seed; never upload its planning references as production data.

## Quote-time checks

- Every LCSC code resolves to the intended manufacturer and exact MPN, not merely a compatible-looking package.
- No unavailable part silently substitutes a different electrical rating.
- JLC preview pin 1, rotation, and board side match the assembly drawing.
- USB connector shell/anchors and all QFN/exposed pads render correctly.
- No paste appears in THT holes unless the selected assembly process explicitly calls for pin-in-paste.
- Board outline, mounting holes, antenna keepout, and connector overhang match the mechanical print.
- J1, Q5/Q6, and J2–J5 are rated and thermally checked from measured simultaneous fan startup/stall current at regulated 12 V; J6 and D1 are rated for controller inrush at 15 V.
- D4/D5 standoff, clamp voltage, pulse energy, and coordination with the upstream protection are documented.
- U5/U6/U7/U12 directions, enables, safe pulls, and 3.3 V domains match the schematic review checklist; U7 is TMUX1511PWR/TSSOP-14, not PCA9306.

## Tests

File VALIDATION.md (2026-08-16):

# ChainAxe Rev A.1 validation snapshot

Date: 2026-08-16  
Status: **engineering prototype source; not a fabrication release**

This snapshot records the checks completed on the editable Rev A.1 source package. It does not authorize a JLCPCB order. The PCB is an intentionally unrouted placement baseline, and this environment does not provide KiCad's native ERC/DRC engine.

## Frozen source hashes

| Artifact | SHA-256 |
|---|---|
| `hardware/chainaxe/chainaxe.kicad_sch` | `c5ab1864315fee64124293f3780d8cc0bd6a481a3dc5e6ae20863bb70655ee61` |
| `hardware/chainaxe/chainaxe.kicad_pcb` | `e64937dc008cee42d53eb6474ec83e666f1a017f1b23b2938610d4655da5476a` |
| `hardware/chainaxe/pin-net-audit.csv` | `3e5f585fd3cf63d26aacb7d06084e4bf2c83de7438b81604c77df4c8e84450b7` |
| `scripts/validate_design.py` | `23e28567653a3e3bc9b8564604b43d3168ab291ee4b6c4cabaad711a4172bd78` |
| `scripts/validate_schematic_pinmap.py` | `246a12f9523711c40cad49b799edd80e29d786da46209838f14d99f81bdfad1f` |
| `scripts/validate_pcb_geometry.py` | `b10e061550c6aa2a80219b5b2b5de76439abe2f889b878b28a4df8e11e710376` |
| `.github/workflows/validate.yml` | `011e3e9b5feaeeae38f4f8b436cb7bbba3678cdee81c814a9c122856ec3bae94` |
| `bom/chainaxe-reva-bom.csv` | `c9a18b48a104538682deb578c80180f2284badda386fc0c7006a98370211bd91` |
| `bom/chainaxe-reva-engineering-bom.xlsx` | `8c8304a6ca015c11219aeed9a3fada36858aaf338fe034fea6cb3433f42a05b4` |

The source was renamed from its working title to ChainAxe, including the KiCad project, project-local library nicknames, BOM files, and documentation. This changed textual source hashes but did not change references, pins, nets, labels, NC markers, component placement, or DNP state. All validators were rerun after the rename.

## Automated checks

Run from the repository root:

```text
python3 scripts/validate_design.py .
python3 scripts/validate_schematic_pinmap.py .
python3 scripts/validate_pcb_geometry.py .
```

Recorded results:

- Design consistency: 267 CSV designators, 6 CSV files, 26 documented connector pins, 159 schematic/BOM footprint matches, 159 schematic/PCB footprint matches, 59 audited PCB connector pads, 163 PCB references, 9 project-local footprint files, 427 schematic labels, and zero errors or warnings.
- Schematic pin map: 159 components, 475 pins, 427 labels, 41 legitimate NC markers, zero expected/actual net mismatches, and zero cross-component endpoint collisions.
- PCB placement geometry: 163 footprints, 495 copper pads, 9 NPTH/mechanical holes, and zero different-net pad, NPTH/copper, component-body/courtyard, or undocumented edge-overhang findings.
- Population state: 13 native DNP components agree between schematic, PCB, and BOM; the S21-safe RESET series link remains open/DNP.
- Engineering BOM: 65 grouped rows and quantity 160, representing all 159 schematic components plus one required external fan fuse. The JLC seed contains 24 fitted-SMT rows; 28 engineering-BOM rows still have a TBD/blank LCSC code.
- Python byte-code compilation of all three validators passed.

These source checks are intentionally independent of KiCad, so they can run in GitHub Actions. They do **not** perform electrical rules, routed-board design rules, field solving, thermal analysis, or physical mating-part verification.

## Explicitly not completed

- KiCad ERC and DRC: not run because `kicad-cli` is unavailable in this environment.
- Routing: zero copper track segments, arcs, and routing vias; net classes are placement/routing intent only.
- JLC stack-up and USB impedance solution: not selected or calculated.
- Gerbers, drill files, CPL/centroid, assembly drawings, and fabrication ZIP: not generated.
- Fan-current copper sizing, Q5/Q6 SOA/current sharing, connector temperature rise, and thermography: not completed.
- AP64501 loop, transient, magnetics, effective ceramic capacitance, and thermal validation: not completed; optional C3 remains DNP.
- Real-part 1:1 fit, mating orientation, keying, and cable continuity for J1, J2–J6, J10, and J30: not completed.
- Exact first hashboard SKU/profile and real Antminer fan MPN validation: not completed.
- Hashboard/fan first article, fault injection, and mining soak: not completed.

## Release rule

Do not generate or order fabrication data until every applicable stop-order item in `design-review-checklist.md` is closed with evidence, native KiCad ERC/DRC passes, the board is routed against the selected JLCPCB process, BOM and CPL are regenerated from that exact source revision, and a five-board first article is reviewed.

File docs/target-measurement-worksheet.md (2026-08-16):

# Target identification and measurement worksheet

Complete one copy for every supported hashboard profile before moving Rev A.1 from schematic entry to fabrication release. Cable fit is common across the target family; ASIC protocol, count, reset policy, voltage-control path, and fast baud are not.

## Identification

| Field | Record |
|---|---|
| Miner SKU (for example S19 XP or S21) | |
| Hashboard label / assembly number | |
| Hashboard PCB revision | |
| ASIC marking and counted quantity | |
| PIC / NoPIC architecture | |
| Original control-board model/revision | |
| Data-cable part / photographs | |
| Profile name and firmware revision tested | |
| Fan manufacturer and MPN | |
| Fan rated voltage/current | |
| Fan connector family/keying | |

Attach clear photographs of the hashboard label, both sides of J10, both ends of the data cable, original-controller connector, and fan plug/socket. Record any factory firmware or EEPROM identity that distinguishes otherwise similar boards.

## Unpowered continuity

Record the connector view used: `mating face / solder side / PCB top / PCB bottom`.

| Position | Expected function | Continuity / observation | Confidence |
|---:|---|---|---|
| 1 | GND | | |
| 2 | GND | | |
| 3 | SDA | | |
| 4 | SCL | | |
| 5 | PLUG | | |
| 6 | A2 | | |
| 7 | A1 | | |
| 8 | A0 | | |
| 9 | GND | | |
| 10 | GND | | |
| 11 | TXD | | |
| 12 | RXD | | |
| 13 | GND | | |
| 14 | GND | | |
| 15 | RESET | | |
| 16 | 3V3 | | |
| 17 | NC | | |
| 18 | NC | | |

Confirm that the exact cable uses a 2×9 shell with positions 17 and 18 unused. Do not substitute a 2×8 connector or omit its keying simply because only 16 positions carry signals.

## Original-controller capture

Only perform powered measurements if equipped to work safely around high-current DC equipment. Keep the hashboard in its original cooling arrangement. Use a ground-referenced differential or isolated measurement method appropriate to the power system; never assume an oscilloscope earth clip can be attached to an arbitrary node.

| Signal | Idle voltage | Active min/max | Source/pull-up side | Timing / notes |
|---|---:|---:|---|---|
| Pin 16 / 3V3 | | | | Startup and shutdown sequence |
| TXD | | | | Initial baud and operational baud |
| RXD | | | | Return-data polarity and timing |
| RESET | | | | Driven, high-impedance, or never touched? |
| PLUG | | | | Inserted/removed levels |
| SDA | | | | Pull-up value/rail if measurable |
| SCL | | | | Frequency and clock stretching |
| A0/A1/A2 | | | | Static strap or sampled function |

Save logic-analyzer captures from cold power-on through ASIC enumeration, including all local-voltage-controller or EEPROM transactions. Record both the conservative bring-up baud and the final operational baud.

### Reset policy gate

| Question | Result |
|---|---|
| May this exact profile drive RESET? | |
| Required polarity and pulse timing | |
| Required state while pin 16 is off | |
| Evidence/source | |
| Firmware unit/integration test name | |

For the S21 BM1368 NoPIC profile, the required result is **controller must never enable or drive RESET**. Verify this electrically across boot, normal mining, software restart, watchdog reset, and every injected fault.

## Hashboard-local voltage and shutdown

Rev A.1 does not communicate with or switch the external PSU. Characterize the hashboard-local control path without treating it as a guaranteed hard disconnect.

| Item | Record |
|---|---|
| Voltage-control device/address | |
| Safe initial command/voltage | |
| Enable/ramp sequence | |
| Telemetry/status available | |
| Local voltage-off/shutdown command | |
| Verified outcome if command succeeds | |
| Failure indication and timeout | |
| Required external power-removal procedure | |

If the local shutdown path fails, Rev A.1 can stop work, disable cable I/O as the profile permits, and run fans at full speed, but it cannot remove hashboard core input power. The test plan must include a safe external disconnect procedure.

## Fan and supply characterization

J1 is an exact regulated 12 V high-current fan input. J6 is a separate 12–15 V low-current logic input. Do not characterize a 15 V fan operating point.

| Fan | Running A at 100% | Startup peak A / duration | Stall behavior | Tach pulses/rev | Minimum reliable PWM/RPM |
|---|---:|---:|---|---:|---|
| 1 | | | | | |
| 2 | | | | | |
| 3 | | | | | |
| 4 | | | | | |

| Power test | Input voltage | Input current | Result / temperatures |
|---|---:|---:|---|
| J1, four-fan simultaneous start | 12.0 V | | |
| J1, worst continuous fan load | 12.0 V | | |
| J6 minimum | 12.0 V | | |
| J6 maximum | 15.0 V | | |
| USB-only logic | 5.0 V | | |
| JP1 closed, verified 12 V J1 | 12.0 V | | |

Use the largest measured simultaneous-start value, connector derating, cable ampacity, ambient-temperature margin, and PCB thermography to set the fuse and copper requirement. Verify each unpowered input remains free of backfeed in every J1/J6/USB/JP1 combination.

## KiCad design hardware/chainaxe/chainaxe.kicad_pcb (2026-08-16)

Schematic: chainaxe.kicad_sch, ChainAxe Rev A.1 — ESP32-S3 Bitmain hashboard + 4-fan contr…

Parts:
C1, C2, C100, C102: 100n; C_0402_1005Metric
C3: 220uF LOW ESR — DNP POST-LOOP VALIDATION; CP_Elec_8x10.2; not fitted
C15: 100n 25V BOOTSTRAP; C_0402_1005Metric
C16: 10n SOFT START; C_0402_1005Metric
C17: 2.7n COMP — DS41980 TABLE 1; C_0402_1005Metric
C18: 56p COMP POLE DNP — DS41980 TABLE 1 C6; C_0402_1005Metric; not fitted
C20, C21: 470uF 25V LOW ESR; CP_Radial_D10.0mm_P5.00mm
C50: 1n CT TO VIN — PROVISIONAL; C_0402_1005Metric
C51: 1u U5 VIN BYPASS; C_0402_1005Metric
C52: 1u HB_3V3 LOCAL; C_0402_1005Metric
C70: 10n; C_0402_1005Metric
C80: 100n U6 VCCA; C_0402_1005Metric
C81: 100n U6 VCCB; C_0402_1005Metric
C101: 1u; C_0805_2012Metric
C103: 100n TMUX VDD; C_0402_1005Metric
C104: 100n U12 VCC; C_0402_1005Metric
C110: 1u EN delay; C_0402_1005Metric
C111: 1n 2kV SHIELD; C_0805_2012Metric
C112: 100nF 50V X7R — U9 VBUS BYPASS; C_0402_1005Metric; LCSC C307331
C200, C201, C202, C203: 100p TACH FILTER DNP; C_0402_1005Metric; not fitted
CIN1, CIN2, CIN3, CIN4: 10uF 50V X7R; C_1210_3225Metric
COUT1, COUT2, COUT3: 22uF 10V X7R; C_0805_2012Metric
D1: SS14 1A 40V; D_SMA; MPN SS14
D2, D3: SS14 1A 40V; D_SMA
D4: SMBJ13A PROVISIONAL; D_SMB; MPN SMBJ13A
D5: SMBJ18CA BIDIRECTIONAL PROVISIONAL; D_SMB; MPN SMBJ18CA
J1: FAN INPUT 12V ONLY — 0455580003; 0455580003_THT; MPN 0455580003; LCSC C492365
J2: FAN 1 — G 12 T P; 0353180420_THT; MPN 0353180420; LCSC C54909
J3: FAN 2 — G 12 T P; 0353180420_THT; MPN 0353180420; LCSC C54909
J4: FAN 3 — G 12 T P; 0353180420_THT; MPN 0353180420; LCSC C54909
J5: FAN 4 — G 12 T P; 0353180420_THT; MPN 0353180420; LCSC C54909
J6: LOGIC IN 12–15V — KEYED TBD; Molex_Micro-Fit_3.0_43650-0200_1x02_P3.00mm_Horizontal
J10: BITMAIN HASHBOARD DATA 2x9 / 18 POS; PM200-2-09-W-4.3_THT; MPN PM200-2-09-W-4.3; LCSC C3012192
J30: USB4105-GF-A — USB2 DEVICE; USB4105-GF-A; MPN USB4105-GF-A; LCSC C2988369
JP1: FAN_TO_LOGIC — DNP; SolderJumper-2_P1.3mm_Open_Pad1.0x1.5mm; not fitted
L1: 3.3uH SRP5030T-3R3M; L_Bourns-SRP5030TA_5.7x5.2mm; MPN SRP5030T-3R3M; LCSC C189931
Q1, Q2, Q3, Q4: 2N7002 OPEN-DRAIN PWM; SOT-23; MPN 2N7002; LCSC C8545
Q5, Q6: DMP3013SFV-7 PROVISIONAL; PowerDI3333-8_DMP3013SFV; MPN DMP3013SFV-7; LCSC C264098
R50: 100k; R_0402_1005Metric
R51: 100R QOD LINK — PROVISIONAL; R_0402_1005Metric
R60: 12k 1%; R_0402_1005Metric
R65: 10.5k COMP — DS41980 TABLE 1; R_0402_1005Metric
R70: 100k 1%; R_0402_1005Metric
R71: 27k 1%; R_0402_1005Metric
R80: 100k OE DISABLE; R_0402_1005Metric
R81: 33R TX; R_0402_1005Metric
R82: 33R RX PROVISIONAL; R_0402_1005Metric
R83: 100k ESP-SIDE PLUG PULLDOWN; R_0402_1005Metric
R84: 100k EN OFF; R_0402_1005Metric
R85, R86, R87, R88, R100, R101, R102: 4.7k; R_0402_1005Metric
R89: 10k RESET OE DISABLE; R_0402_1005Metric
R90: RESET_ENABLE_LINK — 33R DNP FOR S21; R_0402_1005Metric; not fitted
R91: 100k RESET BIAS-UP DNP; R_0402_1005Metric; not fitted
R92: 100k RESET BIAS-DN DNP; R_0402_1005Metric; not fitted
R93, R95, R97: 4.7k DEFAULT LOW; R_0402_1005Metric
R94, R96, R98: 0R HIGH OPTION DNP; R_0402_1005Metric; not fitted
R103: 22k CLK STRAP; R_0402_1005Metric
R104: 33k ADDR STRAP; R_0402_1005Metric
R105: 100k ARM OFF; R_0402_1005Metric
R106: 100k 1% PWM1 SAFE LOW; R_0402_1005Metric
R107: 100k 1% PWM2 SAFE LOW; R_0402_1005Metric
R108: 100k 1% PWM3 SAFE LOW; R_0402_1005Metric
R109: 100k 1% PWM4 SAFE LOW; R_0402_1005Metric
R110: 10k EN pull-up; R_0402_1005Metric
R111: 10k BOOT pull-up; R_0402_1005Metric
R112: 5.1k CC1; R_0402_1005Metric; LCSC C25905
R113: 5.1k CC2; R_0402_1005Metric; LCSC C25905
R114: 22R USB D+; R_0402_1005Metric; LCSC C25105
R115: 22R USB D-; R_0402_1005Metric; LCSC C25105
R116: 1M SHIELD; R_0402_1005Metric
R200, R203, R206, R209: 100k GATE OFF; R_0402_1005Metric
R201, R204, R207, R210: 36k TACH PULLUP; R_0402_1005Metric; LCSC C137999
RFB1: 69.8k 1% — DS41980 TABLE 1; R_0402_1005Metric
RFB2: 22.1k 1% — DS41980 TABLE 1; R_0402_1005Metric
SW1: BOOT; SW_SPST_CK_RS282G05A3; MPN CS1213AGF260; LCSC C5578986
SW2: RESET; SW_SPST_CK_RS282G05A3; MPN CS1213AGF260; LCSC C5578986
TP1: FAN_12V_RAW; TestPoint_Pad_D1.0mm
TP2: FAN_12V; TestPoint_Pad_D1.0mm
TP3: VIN_LOGIC_12_15; TestPoint_Pad_D1.0mm
TP4: LOGIC_IN; TestPoint_Pad_D1.0mm
TP5, TP13: 3V3; TestPoint_Pad_D1.0mm
TP6: HB_3V3; TestPoint_Pad_D1.0mm
TP7: RAIL_MON; TestPoint_Pad_D1.0mm
TP8: DBG_TX; TestPoint_Pad_D1.0mm
TP9: DBG_RX; TestPoint_Pad_D1.0mm
TP10: EXP_GPIO5; TestPoint_Pad_D1.0mm
TP11: EXP_GPIO6; TestPoint_Pad_D1.0mm
TP12: GND; TestPoint_Pad_D1.0mm
TP14: FAN_PWM1; TestPoint_Pad_D1.0mm
TP15: FAN_TACH1; TestPoint_Pad_D1.0mm
TP16: FAN_PWM2; TestPoint_Pad_D1.0mm
TP17: FAN_TACH2; TestPoint_Pad_D1.0mm
TP18: FAN_PWM3; TestPoint_Pad_D1.0mm
TP19: FAN_TACH3; TestPoint_Pad_D1.0mm
TP20: FAN_PWM4; TestPoint_Pad_D1.0mm
TP21: FAN_TACH4; TestPoint_Pad_D1.0mm
TP22: FAN_ARM; TestPoint_Pad_D1.0mm
TP23: FAN_ALERT_N; TestPoint_Pad_D1.0mm
TP24: FAN_SDA; TestPoint_Pad_D1.0mm
TP25: FAN_SCL; TestPoint_Pad_D1.0mm
TP26: USB_VBUS; TestPoint_Pad_D1.0mm
TP27: HB_RESET_CMD; TestPoint_Pad_D1.0mm
TP28: HB_IO_PWR_EN; TestPoint_Pad_D1.0mm
TP29: HB_TX; TestPoint_Pad_D1.0mm
TP30: HB_RX; TestPoint_Pad_D1.0mm
TP31: HB_PLUG; TestPoint_Pad_D1.0mm
TP32: HB_SDA; TestPoint_Pad_D1.0mm
TP33: HB_SCL; TestPoint_Pad_D1.0mm
TP34: HB_RESET; TestPoint_Pad_D1.0mm
TP35: HB_XLAT_OE_N; TestPoint_Pad_D1.0mm
TP36: HB_I2C_EN; TestPoint_Pad_D1.0mm
TP37: HB_RESET_OE_N; TestPoint_Pad_D1.0mm
U1: ESP32-S3-WROOM-1-N16R8; ESP32-S3-WROOM-1_v1.8; MPN ESP32-S3-WROOM-1-N16R8; LCSC C2913202
U2: EMC2305-1-AP-TR; EMC2305_QFN16_4x4_P0.65_EP2.2; MPN EMC2305-1-AP-TR; LCSC C621415
U3: AP64501SP-13 — 3V3 BUCK PROVISIONAL; AP64501_SO8EP; MPN AP64501SP-13; LCSC C2071517
U5: TPS22917DBVR — HB 3V3 SWITCH; SOT-23-6; MPN TPS22917DBVR; LCSC C2681320
U6: SN74AXC4T774PWR — UART/PLUG GATED; TSSOP-16_4.4x5mm_P0.65mm; MPN SN74AXC4T774PWR; LCSC C1849453
U7: TMUX1511PWR — GATED HB I2C; TSSOP-14_4.4x5mm_P0.65mm; MPN TMUX1511PWR; LCSC C2866750
U8: SN74LVC126APWR — FAN PWM ARM; TSSOP-14_4.4x5mm_P0.65mm; MPN SN74LVC126APWR
U9: USBLC6-2SC6; SOT-23-6; MPN USBLC6-2SC6; LCSC C7519
U10, U11, U13: TPD4E05U06DQAR; TI_DQA0010A_USON10_2.5x1.0_P0.5; MPN TPD4E05U06DQAR; LCSC C138714
U12: SN74LVC1G125DBVR — RESET GATE; SOT-23-5; MPN SN74LVC1G125DBVR
ZD1: BZX84C12LT1G 12V VGS clamp; SOT-23; MPN BZX84C12LT1G; LCSC C82475

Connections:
3V3: C1.1, C2.1, C3.1, C50.2, C51.1, C80.1, C100.1, C101.1, C102.1, COUT1.1, COUT2.1, COUT3.1, L1.2, R80.2, R85.2, R86.2, R89.2, R100.2, R101.2, R102.2, R103.2, R104.2, R110.1, R111.1, R201.2, R204.2, R207.2, R210.2, RFB1.1, TP5.1, TP13.1, U1.2 (3V3), U2.3 (VDD), U5.1 (VIN), U6.1 (DIR1), U6.8 (DIR4), U6.16 (VCCA), U8.14 (VCC)
BOOT_N: R111.2, SW1.1, U1.27 (GPIO0/BOOT*)
BUCK_BST: C15.1, U3.1 (BST)
BUCK_COMP: C18.1, R65.1, U3.6 (COMP)
BUCK_COMP_RC: C17.1, R65.2
BUCK_FB: RFB1.2, RFB2.1, U3.5 (FB)
BUCK_SS: C16.1, U3.4 (SS)
BUCK_SW: C15.2, L1.1, U3.8 (SW)
DBG_RX: TP9.1, U1.36 (U0RXD/GPIO44/CLK_OUT2)
DBG_TX: TP8.1, U1.37 (U0TXD/GPIO43/CLK_OUT1)
EMC_ADDR: R104.1, U2.4 (ADDR_SEL)
EMC_CLK: R103.1, U2.11 (CLK)
EMC_PWM1: R106.1, U2.5 (PWM1), U8.2 (1A)
EMC_PWM2: R107.1, U2.7 (PWM2), U8.5 (2A)
EMC_PWM3: R108.1, U2.9 (PWM3), U8.9 (3A)
EMC_PWM4: R109.1, U2.13 (PWM4), U8.12 (4A)
ESP_EN: C110.1, R110.2, SW2.1, U1.3 (EN)
EXP_GPIO5: TP10.1, U1.5 (GPIO5/TOUCH5/ADC1_CH4)
EXP_GPIO6: TP11.1, U1.6 (GPIO6/TOUCH6/ADC1_CH5)
FAN_12V: C20.1, C21.1, D4.1 (K), J2.2, J3.2, J4.2, J5.2, JP1.1 (A), Q5.1 (SOURCE), Q5.2 (SOURCE), Q5.3 (SOURCE), Q6.1 (SOURCE), Q6.2 (SOURCE), Q6.3 (SOURCE), R70.1, TP2.1, ZD1.3 (K)
FAN_12V_RAW: J1.4, J1.5, J1.6, Q5.5 (DRAIN), Q5.6 (DRAIN), Q5.7 (DRAIN), Q5.8 (DRAIN), Q6.5 (DRAIN), Q6.6 (DRAIN), Q6.7 (DRAIN), Q6.8 (DRAIN), TP1.1
FAN_ALERT_N: R102.1, TP23.1, U1.21 (GPIO13/TOUCH13/ADC2_CH2/FSPIQ/FSPIIO7/S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), U2.12 (~ALERT)
FAN_ARM: R105.1, TP22.1, U1.12 (GPIO8/TOUCH8/ADC1_CH7/SUBSPICS1), U8.1 (1OE), U8.4 (2OE), U8.10 (3OE), U8.13 (4OE)
FAN_GATE1: Q1.1 (G), R200.1, U8.3 (1Y)
FAN_GATE2: Q2.1 (G), R203.1, U8.6 (2Y)
FAN_GATE3: Q3.1 (G), R206.1, U8.8 (3Y)
FAN_GATE4: Q4.1 (G), R209.1, U8.11 (4Y)
FAN_PWM1: J2.4, Q1.3 (D), TP14.1
FAN_PWM2: J3.4, Q2.3 (D), TP16.1
FAN_PWM3: J4.4, Q3.3 (D), TP18.1
FAN_PWM4: J5.4, Q4.3 (D), TP20.1
FAN_RPP_GATE: Q5.4 (GATE), Q6.4 (GATE), R60.1, ZD1.1 (A)
FAN_SCL: R101.1, TP25.1, U1.25 (GPIO48/SPICLK_N/SUBSPICLK_N_DIFF), U2.2 (SMCLK)
FAN_SDA: R100.1, TP24.1, U1.24 (GPIO47/SPICLK_P/SUBSPICLK_P_DIFF), U2.1 (SMDATA)
FAN_TACH1: C200.1, J2.3, R201.1, TP15.1, U2.6 (TACH1)
FAN_TACH2: C201.1, J3.3, R204.1, TP17.1, U2.8 (TACH2)
FAN_TACH3: C202.1, J4.3, R207.1, TP19.1, U2.10 (TACH3)
FAN_TACH4: C203.1, J5.3, R210.1, TP21.1, U2.14 (TACH4)
FAN_TO_LOGIC_FEED: D2.2 (A), JP1.2 (B)
GND: C1.2, C2.2, C3.2, C16.2, C17.2, C18.2, C20.2, C21.2, C51.2, C52.2, C70.2, C80.2, C81.2, C100.2, C101.2, C102.2, C103.2, C104.2, C110.2, C111.2, C112.2, C200.2, C201.2, C202.2, C203.2, CIN1.2, CIN2.2, CIN3.2, CIN4.2, COUT1.2, COUT2.2, COUT3.2, D4.2 (A), D5.2 (A2), J1.1, J1.2, J1.3, J2.1, J3.1, J4.1, J5.1, J6.2, J10.1, J10.2, J10.9, J10.10, J10.13, J10.14, J30.A1 (GND), J30.A12 (GND), J30.B1 (GND), J30.B12 (GND), Q1.2 (S), Q2.2 (S), Q3.2 (S), Q4.2 (S), R50.2, R60.2, R71.2, R83.2, R84.2, R92.2, R93.2, R95.2, R97.2, R105.2, R106.2, R107.2, R108.2, R109.2, R112.2, R113.2, R116.2, R200.2, R203.2, R206.2, R209.2, RFB2.2, SW1.2, SW2.2, TP12.1, U1.1 (GND), U1.40 (GND), U1.41 (GND), U2.17 (GND), U3.7 (GND), U3.9 (EP), U5.2 (GND), U6.2 (DIR2), U6.6 (A4), U6.7 (DIR3), U6.10 (GND), U7.7 (GND), U7.10 (SEL3), U7.13 (SEL4), U8.7 (GND), U9.2 (GND), U10.3 (GND), U10.8 (GND), U11.3 (GND), U11.8 (GND), U12.3 (GND), U13.3 (GND), U13.8 (GND)
HB_3V3: C52.1, C81.1, C103.1, C104.1, J10.16, R51.1, R87.2, R88.2, R91.2, R94.2, R96.2, R98.2, TP6.1, U5.6 (VOUT), U6.15 (VCCB), U7.14 (VDD), U12.5 (VCC)
HB_3V3_CT: C50.1, U5.4 (CT)
HB_A0: J10.8, R93.1, R94.1, U11.2 (D1-)
HB_A1: J10.7, R95.1, R96.1, U11.1 (D1+)
HB_A2: J10.6, R97.1, R98.1, U10.5 (D2-)
HB_I2C_EN: R84.1, TP36.1, U1.17 (GPIO9/TOUCH9/ADC1_CH8/FSPIHD/SUBSPIHD), U7.1 (SEL1), U7.4 (SEL2)
HB_IO_PWR_EN: R50.1, TP28.1, U1.18 (GPIO10/TOUCH10/ADC1_CH9/FSPICS0/FSPIIO4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), U5.3 (ON)
HB_PLUG: J10.5, TP31.1, U6.12 (B3), U10.4 (D2+)
HB_PLUG_3V3: R83.1, U1.20 (GPIO12/TOUCH12/ADC2_CH1/FSPICLK/FSPIIO6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), U6.5 (A3)
HB_QOD: R51.2, U5.5 (QOD)
HB_RESET: J10.15, R90.2, R91.1, R92.1, TP34.1, U13.1 (D1+)
HB_RESET_CMD: TP27.1, U1.39 (GPIO1/TOUCH1/ADC1_CH0), U12.2 (A)
HB_RESET_DRV: R90.1, U12.4 (Y)
HB_RESET_OE_N: R89.1, TP37.1, U1.4 (GPIO4/TOUCH4/ADC1_CH3), U12.1 (OE_N)
HB_RX: J10.12, R82.1, TP30.1, U11.5 (D2-)
HB_RX_3V3: U1.11 (GPIO18/U1RXD/ADC2_CH7/CLK_OUT3), U6.4 (A2)
HB_RX_BUF: R82.2, U6.13 (B2)
HB_SCL: J10.4, R87.1, TP33.1, U7.3 (D1), U10.2 (D1-)
HB_SCL_3V3: R85.1, U1.23 (GPIO21), U7.2 (S1)
HB_SDA: J10.3, R88.1, TP32.1, U7.6 (D2), U10.1 (D1+)
HB_SDA_3V3: R86.1, U1.22 (GPIO14/TOUCH14/ADC2_CH3/FSPIWP/FSPIDQS/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), U7.5 (S2)
HB_TX: J10.11, R81.2, TP29.1, U11.4 (D2+)
HB_TX_3V3: U1.10 (GPIO17/U1TXD/ADC2_CH6), U6.3 (A1)
HB_TX_BUF: R81.1, U6.14 (B1)
HB_XLAT_OE_N: R80.1, TP35.1, U1.7 (GPIO7/TOUCH7/ADC1_CH6), U6.9 (OE)
LOGIC_IN: CIN1.1, CIN2.1, CIN3.1, CIN4.1, D1.1 (K), D2.1 (K), D3.1 (K), TP4.1, U3.2 (VIN), U3.3 (EN)
RAIL_MON: C70.1, R70.2, R71.1, TP7.1, U1.19 (GPIO11/TOUCH11/ADC2_CH0/FSPID/FSPIIO5/S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)
USB_CC1: J30.A5 (CC1), R112.1
USB_CC2: J30.B5 (CC2), R113.1
USB_DN: R115.2, U1.13 (GPIO19/U1RTS/ADC2_CH8/CLK_OUT2/USB_D-)
USB_DN_CONN: J30.A7 (D-), J30.B7 (D-), U9.3 (I/O2)
USB_DN_PROT: R115.1, U9.4 (I/O2)
USB_DP: R114.2, U1.14 (GPIO20/U1CTS/ADC2_CH9/CLK_OUT1/USB_D+)
USB_DP_CONN: J30.A6 (D+), J30.B6 (D+), U9.1 (I/O1)
USB_DP_PROT: R114.1, U9.6 (I/O1)
USB_SHIELD: C111.1, J30.S1 (SHIELD), R116.1
USB_VBUS: C112.1, D3.2 (A), J30.A4 (VBUS), J30.A9 (VBUS), J30.B4 (VBUS), J30.B9 (VBUS), TP26.1, U9.5 (VBUS)
VIN_LOGIC_12_15: D1.2 (A), D5.1 (A1), J6.1, TP3.1

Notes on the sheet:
CHAINAXE REV A.1 — PRELIMINARY / NOT FOR FABRICATION
POWER + PROTECTION (J1 regulated 12V fan power; J6 controller-only 12–15V)
ESP32-S3 + USB / DEBUG
HASHBOARD CABLE INTERFACE — COMMON 2x9 / 18-POSITION FORM
FAN CONTROL — 4x ANTHAT-STYLE 12V 4-WIRE
DANGER / S21 ASSEMBLY RULE: leave R90 RESET_ENABLE_LINK OPEN/DNP. Firmware must also never enable U12. Hardware safety is not firmware-only.
SAFE STARTUP: R105 keeps FAN_ARM=0 and R106-R109 hold U8 PWM inputs low; sinks stay released/full-speed-safe. HB_3V3=OFF; U6/U7/U12 disabled or high-Z. Prove every state on hardware.
NO PSU CONTROL ON REV A.1. Hashboard core power remains external; an interface fault cannot guarantee removal of ASIC core power.
J1/fan copper is high current. External fuse required near source. Select FET count, connector, copper, and thermals from measured simultaneous startup/stall current.
FAN PROFILE RULE: supported 4-wire fans must include their own PWM pull-up. ChainAxe provides open-drain sinks only; fans needing an external pull-up are unsupported.
HASHBOARD POWER RULE: J10 pin16 HB_3V3 is controller-sourced only through U5. Never externally drive or backfeed this rail while R51 QOD is populated.
All connector drawings are mating-face views. Continuity-check pin 1, keying, fan G/12/T/P, J10 positions 17/18 NC, and shared ground before power.
PROVISIONAL/TBD: J6 selection and all connector fit checks; AP64501 compensation/magnetics; TVS ratings; FET thermals; EMC2305 straps; exact S19/S21 profile.
JLCPCB intent: 4-layer, mostly 0402/0805; extended parts accepted; J1/J2-J5/J10 hand-install. Verify fresh manufacturer-drawing footprints with 1:1 prints.
Source basis: bitaxeorg/bitaxeNaja, skot/aditBoard, skot/AntHat, and manufacturer datasheets. Independently audit every critical symbol and footprint before fabrication.

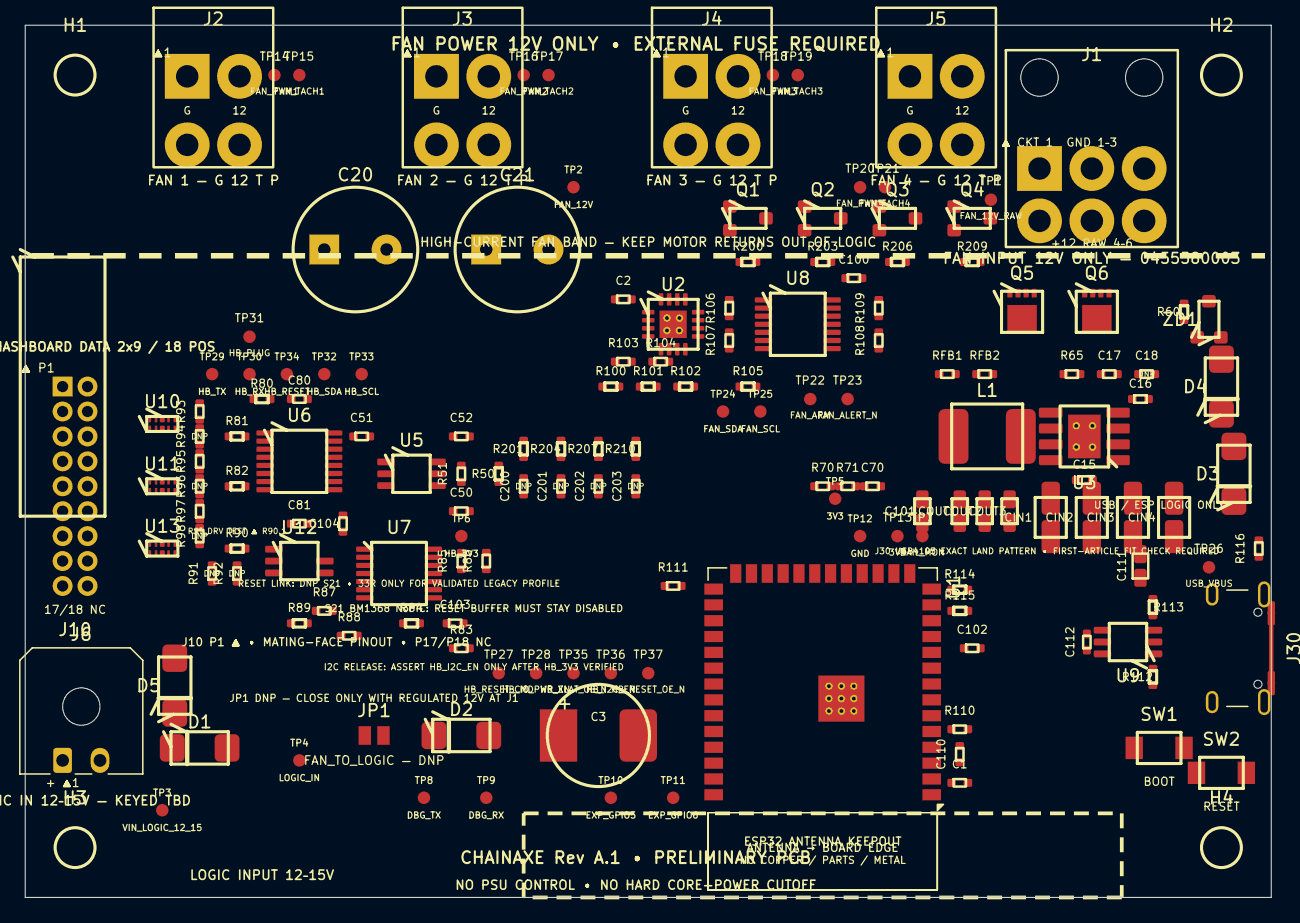
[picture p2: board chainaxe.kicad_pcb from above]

Board: 4 copper layers, 100.0 x 70.0 mm, 163 parts (0 on the bottom side), 78 nets, no tracks yet.

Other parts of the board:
H1, H2, H3, H4: M3; MountingHole_3.2mm_M3

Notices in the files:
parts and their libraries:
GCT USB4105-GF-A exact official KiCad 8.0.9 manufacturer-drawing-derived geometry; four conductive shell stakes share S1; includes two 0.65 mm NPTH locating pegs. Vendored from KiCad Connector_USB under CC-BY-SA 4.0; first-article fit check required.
